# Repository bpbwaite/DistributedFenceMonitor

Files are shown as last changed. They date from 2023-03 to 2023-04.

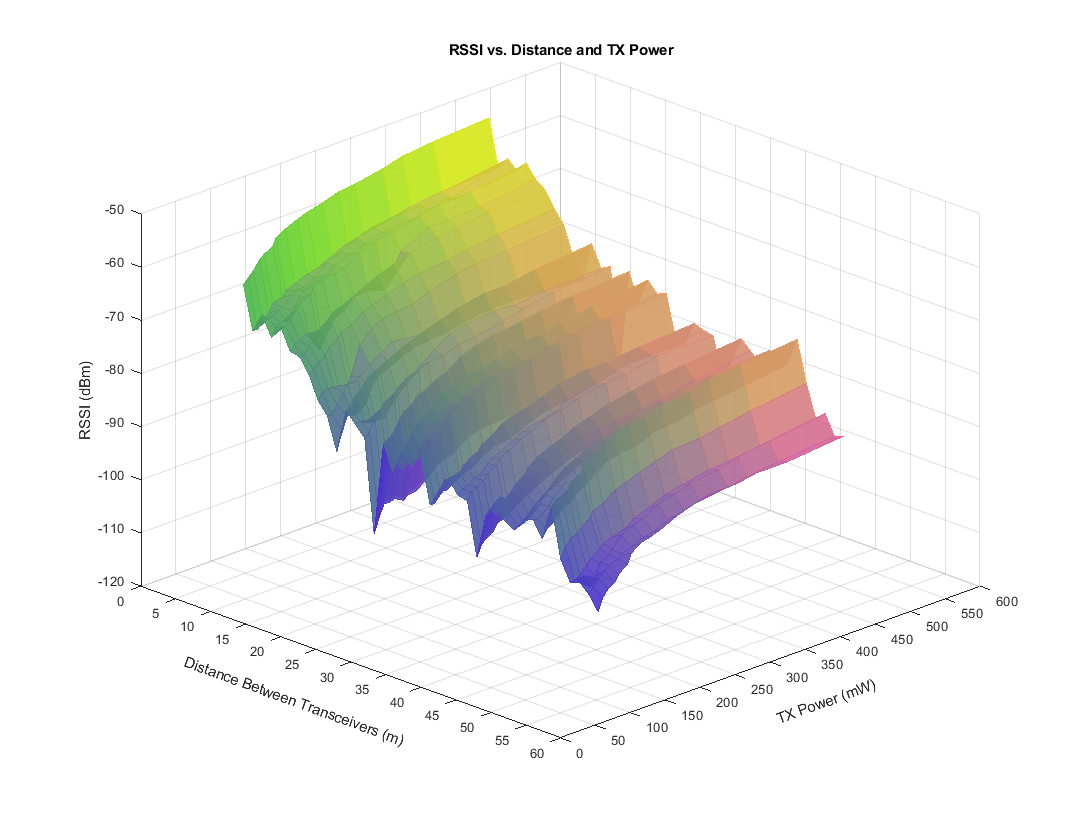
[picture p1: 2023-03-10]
interpreter/Improved Russey Tests/result.png

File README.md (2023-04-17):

# DistributedFenceMonitor

Repository for the Embry-Riddle Aeronautical University Distributed Fence Monitor Capstone.

*In Association with ICARUS and ERP.*

## How to Use

- The node source file is 'src/dfm_mkr1310.cpp'.
- The central-node source file is 'src/dfm_recv_mkr1310.cpp'.
- The central server file is 'interpreter/dfm_recv.m'
- The "main.cpp" is set up so that PlatformIO can compile and upload multiple sources separately, depending on the environment.

### Project Members

- Briellyn Braithwaite
- Jack Ramsay
- Lucas Marin
- Mike Paff
- Renzo Mena
- Zachary Couch

### Advisors

- Dr. Zapata
- Dr. Aranzazu
- Dr. Bruder
- Dr. Dorfling
- Dr. Sevic

## Configuration Features

All values settable in *dfm_mkr1310.h*

### System

- Node Identifier
- Peripheral Connection Reattempts (default: 5)
- Debug Interface on/off (default: on)
- Debug Interface Speed (default: 115200)
- Debug Interface Timeout (default: 10 sec)
- ADC Bit Depth (default: 10, max: 12)

### Motion Sensing

- Sample Rate (default: 100 Hz, max: 400 Hz)
- Sensitivity (default: 2g)
- Activity Threshold (default: 00007, min: 00002)
- Inactive Timer (default: 0.8 sec, min: 0.8)
- Severity Thresholds
- Resolution (default: 10 bit @ 256 LSB/g)

### Timing

- Reporting Interval (default: 15 sec, min: 5)
- Maximum Readings to Take (default: 2x)
- Sampling Duration (default: 500 samples, max: 2000)
- Data Timeout (default: 50 ms)

### Calibration

- Calibration Interval (default: 15 minutes, min: 1, max: 15)
- Calibration Duration (default: 300 samples)
- Calibration Time Slice (default: 0.5 sec, min: 0.5, max: 2.0)

### Low-Pass Filter

- Cutoff Frequency (default: 8 Hz)
- Impulse Response Length (default: 16)

### PCB Wiring Configuration

- Pinout
  - Mode pin (default: 2)
  - Status pin (default: 6)
  - Error pin (default: 3)
  - Battery pin (default: A1)
  - Switch pin (default: A5)
  - CS pin for ADXL1 (default: A3)
  - CS pin for ADXL2 (default: A4)
  - Interrupts pin (default: 7)
  - Temperature pin (default: 4)
- Resistor Voltage Divider Values (default: 680k/330k)

### LoRa Configuration

- Transmission Frequencies (default: 914.9 MHz)
- Transmission Power (default: 4dB, min: 2, max: 17)
- Acknowledgement Timeout (default: 1 sec)
- Reject CRC Failures (default: false)
- Bandwidth (default: 125kHz, max: 250kHz)
- Spreadfactor (default: 7, min: 7, max: 12)
- Syncword (default: 0012)

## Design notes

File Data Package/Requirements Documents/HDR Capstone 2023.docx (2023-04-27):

# Hardware Design Requirements

# Distributed Fence Vibration Monitor System

Version 1.1

Prepared by

B. Braithwaite

L. Marin

Embry-Riddle Aeronautical University

# 1 Introduction: High-Level Architecture

## 1.1 Purpose, Intended Audience and Reading Suggestions.

This document will serve as a reference to how the hardware is connected and configured along with requirements that drive those parameters. The intended audience are those continuing the development of this system and those who are maintaining this system. This document is intended to be read as a set of requirements and primary reference to other documentation, the goal is to describe how the system was designed.

## 1.2 Operating Environment

The end product is being designed for use in South African game reserves. But these requirements are set for a proof of concept system that will be used in the area of Prescott Arizona, primarily during the ERAU fall and spring semesters by students and faculty for research purposes.

## 1.3 Assumptions and Dependencies

This document largely assumes that the platform in use has already been determined and is the MKR1310. These requirements assume that this is a research project that will be used by ERAU students and faculty. Because this system will be deployed for relatively small scale research, it is assumed that all components in the system will be easily accessible for maintenance and repairs.

## 1.4 Product Scope & Constraints

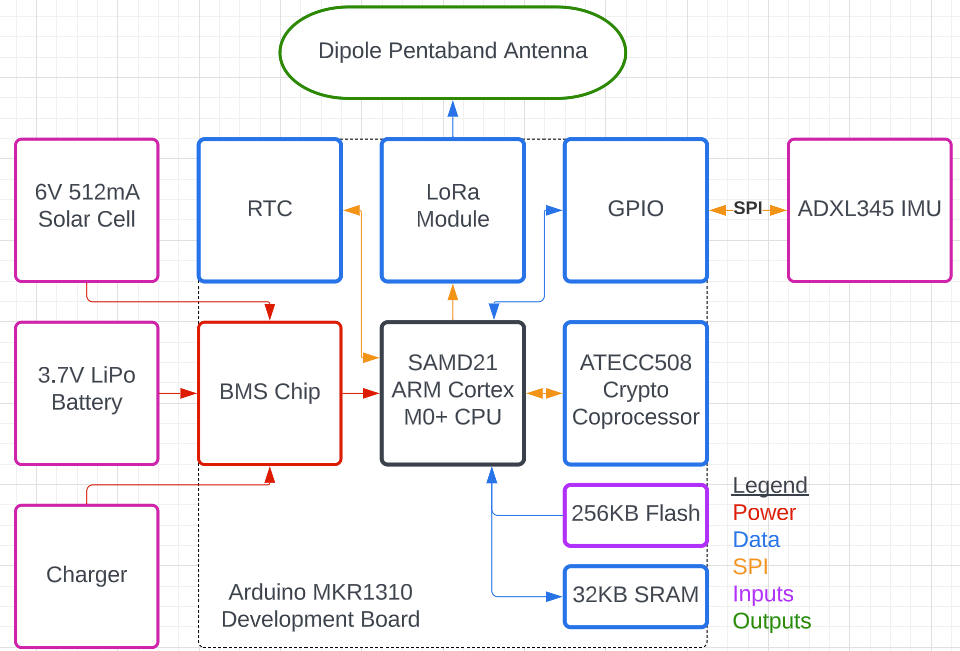
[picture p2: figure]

Figure 1 - Implementation Specific High-Level Hardware Diagram

# 2 Hardware Features

## 2.1 Individual Nodes Hardware

MKR1310 Device | Minimum Value | Preferred Value
Power Connectors | On-board battery connector (mini-JST) | USB, JST, terminal or barrel
Accelerometer Compatibility | ADXL345 | ADXL345, ADXL355
Wireless Capability | LoRa | LoRa
Headers | Optional | 10 for test, 30 I/O
Mode Switches | Mode switch | Yes (DIP switch, various)
Programmability | Micro-USB | Micro-USB
Debug Interfaces | Optional | Serial/UART or JTAG
Mounting Options | PCB mounting holes | PCB mounting holes, protective case

## 2.2 Central Server Hardware

The central receiver is physically similar to one of the nodes, but does not need the sensor capabilities, as the central receiver is loaded with a unique program to differentiate it from the nodes.

MKR1310 Device | Minimum Value | Preferred Value
Wireless Capability | LoRa | LoRa
Mode Switches | None | Mode Switch
Programmability & Interfacing | Micro-USB | Micro-USB

# 3 Physical & Mechanical Requirement Specifications

HR 1 The device shall be inexpensive
  1.1. Developmental units cost $135 each
  1.2. First SMD prototype expected to cost ~$40
HR 2 The device shall be self-contained
  2.1. Any computer, sensors, antenna, battery, and solar are all to be affixed in or on the unit
  2.2. There is no wired tethering to another device when operating
  2.3. Should electrical grounding be necessary, the device may simply contact the fence
HR 3 The device shall be weatherproof
  3.1. The housing of the unit shall be water and dust resistant to IP66 standards
  3.2. Temperature resistance
  3.3. UV resistance (don’t melt or discolor)
HR 4 The device shall be easy to install
  4.1. One person can handle multiple (5-10) units at a time
    4.1.1. The casing of the units must be stackable
  4.2. The units must be easy to transport
    4.2.1. [NTH] Fit snugly in a rectangular crate
  4.3. Each unit shall weigh less than 400g
  4.4. Installation must be repeatable
    4.4.1. Attachment to the fence is facilitated by a reusable clip

# 4 Electrical Requirement Specifications

HR 5 The device must accept energy from multiple power sources
  5.1. Battery management system (BMS): capable of battery, solar, and charging
  5.2. Solar panel in the range 5-7 V, capable of 512mA
    5.2.1. The MKR1310 BMS requires 512mA to charge a battery [1]
    5.2.2. 2-4A is recommended for greater efficiency [1]
  5.3. A Lithium-Polymer (LiPo) battery [2]
    5.3.1. Nominal voltage 3.7V-3.8V
    5.3.2. At least 1024mAh capacity [2]
    5.3.3. The battery must supply at least 150mA when loaded down to 3.3V
    5.3.4. The LoRa module may consume 128mA [1], and we need some overhead
    5.3.5. Absolute minimum viability: 48 hours
  5.4. [NTH] USB charger capable of 5V ±5% and at least 1000mA DC
HR 6 The device shall decouple from its power supply
  6.1. A 200uF decoupling cap on 5V rail has been recommended by many to avoid tripping OCP at high transmission strengths
HR 7 The device shall be capable of multiple power modes
  7.1. Power consumption is measured WRT the 3.3V rail
  7.2. ULP sleep mode
    7.2.1. ~100 µA [2]
  7.3. Processing mode
    7.3.1. 6-30 mA [3]
  7.4. High power transmitting mode
    7.4.1. Up to 128 mA [1] with Power Amplifier Boost

# 5 Hardware Requirement Specifications

HR 8 The device must contain a microcomputer
  8.1. A flash memory capable of holding the compiled software as described in the SRS document
  8.2. Processing ability to perform the functions as described in the SRS
    8.2.1. With interrupt abilities
    8.2.2. With RTC abilities
HR 9 The device must implement an accelerometer or IMU
  9.1. The maximum sampling rate must be at least 80 Hz
HR 10 The device must implement an RF transceiver
  10.1. Radio communications shall adhere to local regulations
  10.2. The radio must implement American (915MHz) and African (868MHz) LoRa frequencies
HR 11 The prototype shall be built upon a useful PCB platform
  11.1. The PCB must have power and status indicator LEDs
  11.2. There must be a physical switch to facilitate any changes in modes or configuration

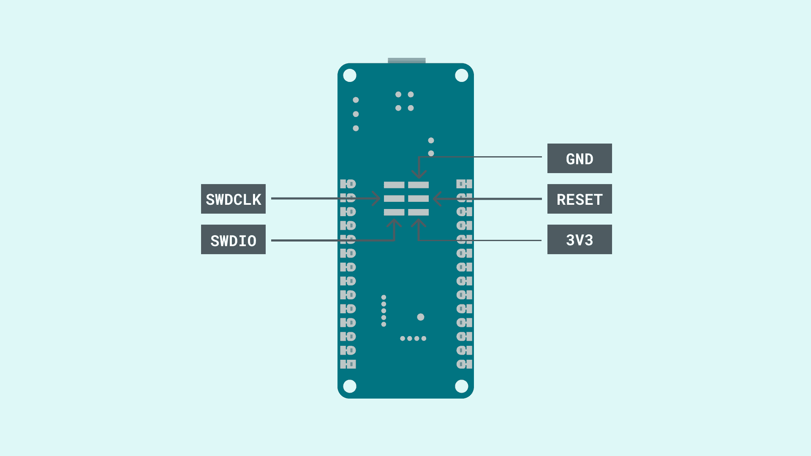
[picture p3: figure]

  11.3. The board must extend and support the MCU SWD interface [4]

Figure 2 - MKR1310 JTAG Interface Pinout

# 6 Acronyms and Abbreviations

The below table contains acronyms and abbreviations used in this document.

| Abbreviation | Description
A | ADC | Analog to Digital Converter
| ADXL | Analog Devices accelerometer
| AGC | Automatic Gain Control
B | BER | Bit Error Rate
| BLE | Bluetooth Low Energy
| BMS | Battery Management System
| BW | Bandwidth
C | CLK | Clock
| CPU | Central Processing Unit
| CRC | Cyclic Redundancy Check
D | dBm | Decibel Milliwatts
| DAC | Digital to Analog Converter
| DC | Direct Current
| DFM | Distributed Fence Monitor
| DIP | Dual In-line Package
E | EEPROM | Electrically Erasable Programmable Read-Only Memory
| EasyEDA | Schematic capture and circuit board design software
F | FCC | Federal Communications Commission
| FIFO | First In, First Out
| FSK | Frequency-shift Keying
| FXOSC | Frequency of Crystal Oscillator
G | g | grams
| GPIO | General Purpose Input/Output
H | HDR | Hardware Design Requirements
I | I2C, IIC | Inter-Integrated Circuit
| IC | Integrated Circuit
| IO, I/O | Input/Output
| IP | Ingress Protection rating
| IRQ | Interrupt Request
J | JST | Japan Solderless Terminal
| JTAG | Joint Test Action Group
K | kHz | Kilohertz
L | LED | Light Emitting Diode
| LiPo | Lithium Polymer battery
| LNA | Low Noise Amplifier
| LoRa | Long Range low-power wide-area network
M | mA | milliamperes
| mAh | milliamp Hour
| MCU | Micro Controller
| MHz | Megahertz
| MISO | Main In, Serial Out
| MKR1310 | An Arduino development platform with LoRa
| MOSI | Main Out, Serial In
| MPU | Motion Processing Unit
N | NTH | Nice To Have
O | OCP | Overcurrent Protection
| OOK | On-off keying
| OTA | Over the Air
P | PA | Power Amplifier
| PCB | Printed Circuit Board
| PLL | Phase-Locked Loop
| PMIC | Power Management Integrated Circuit
| PSU | Power Supply
R | RAM, SRAM | Random Access Memory
| RF | Radio Frequency
| RSSI | Received Signal Strength Indicator
| RTC | Real Time Clock
| RX | Receive
S | SF | Spread Factor
| SMD | Surface Mount Device
| SNR | Signal to Noise Ratio
| SPI | Serial Peripheral Interface
| SRS | Software Requirements Specifications
| SW | Synchronization Word
| SWD | Serial Wire Debug
T | TOA | Time on Air
| TRNG | True Random Number Generator
| TX | Transmit
U | uA, µA | microamperes
| UART | Universal Asynchronous Receiver-Transmitter
| uF, µF | microfarads
| ULP | Ultra Low Power
| USB | Universal Serial Bus
| UV | Ultraviolet Light
| uW, µW | microwatts
V | V | Volts
W | WAN | Wide Area Network
| WDT | Watchdog Timer
| WRT | With Respect To

# 7 Revision History

Date | Revision | Changes
1/26/2023 | 1.0 | First Release
2/9/2023 | 1.1 | Draft

# 8 References

[1] | FCC, "Arduino MKR WAN 1310 Product Datasheet," 2020. [Online]. Available: https://fcc.report/FCC-ID/2AN9S-ABX00029/5077682.pdf.
[2] | Arduino S.r.l., "Arduino MKR WAN 1310," 2021. [Online]. Available: https://store-usa.arduino.cc/products/arduino-mkr-wan-1310?selectedStore=us.
[3] | Microchip Technology Inc., "SAM D21 Family," 2018. [Online]. Available: https://content.arduino.cc/assets/mkr-microchip_samd21_family_full_datasheet-ds40001882d.pdf.
[4] | Arduino, "Debugging SAM-Based Arduino Boards with Atmel-ICE," 2023. [Online]. Available: https://docs.arduino.cc/tutorials/mkr-wifi-1010/atmel-ice.

006-0119-02 Hardware Design Requirements Documentation 2

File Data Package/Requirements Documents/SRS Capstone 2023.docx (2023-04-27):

# Software Requirements Specification

# Distributed Fence Vibration Monitor System

Version 1.1

Prepared by

J. Ramsay

B. Braithwaite

R. Mena

M. Paff

Embry-Riddle Aeronautical University

# 1 Introduction

## 1.1 Purpose

The purpose of the Software Requirement Specification is to provide documentation for the software aspects of the Distributed Fence Vibration System. This document provides both non-functional and functional requirements. It is intended to be used to reference the functionality and design of the system within the scope of hardware and software. The document will present software specifications for the individual nodes and its components and the central server as a secondary requirement.

## 1.2 Document Conventions

Refer to [CML for style guide] for reference to design.

## 1.3 Intended Audience and Reading Suggestions

This Software Requirements Specification (SRS) document is primarily intended for the engineering team and design leads. It is suggested that this document be read with and referenced with the Hardware Requirement Specifications.

## 1.4 Programming Environment

The components of the system shall be programmed using Visual Studio Code version 1.75. The MKR1310 as well as the RP2040 will be independent of each other with environments set up within an extension called Platform IO that is supported by Visual Studio Code. Platform IO is an extension that will allow for building and uploading of Arduino libraries and scripts for the individual boards. The Arduino mbed OS Nano board manager and the Arduino SAMD 32-bit Cortex M0+ will be installed from the Arduino IDE but supported and managed by Platform IO within Visual Studio Code. The files for each board consists of a header file and a source code file. Additional build flags in a configuration file enable advanced setup.

## 1.5 Dependency Tree

- Source Files
  - dfm_mkr1310.cpp
    - dfm_mkr1310.h
    - adafruit_ADXL345_U.h
    - Arduino.h
      - ArduinoCore API for ….
    - ArduinoECCX08.h
    - ArduinoLowPower.h
    - LoRa.h
      - SPI.h
    - RTCZero.h
      - SPI.h
  - dfm_nanorp2040.cpp
    - Arduino.h
    - Arduino_LSM6DSOX.h
    - WiFiNINA.h
  - dfm_vecv_mkr1310.cpp
    - Arduino.h
    - ARduinoECCX08.h
    - LoRa.h
    - SPI.h
  - dfm_recv_nanorp2040.cpp
    - Arduino.h
    - WiFiNINA.h
  - main.cpp
    - Arduino.h
    - dfm_vecv_mkr1310.h
    - dfm_nanorp2040.h

# 2 System Features (Functional Requirements)

## 2.1 Motion Detection

The software shall include a feature that detects motion from the chosen IMU and convert that motion into readable and transcribe data to then be used for other requirements. The software will include and depend on the libraries given from the chosen board and the components. This system feature holds the highest priority of all other software features as it is the core fundamental aspect of the project. The motion detection shall be interpreted and managed by the MKR1310 (or RP2040).

## 2.2 Communication

Communication between each of the nodes and the central server will be done by LoRa and a created struct contained within the dfm_mkr1310.h file will be transmitted using LoRa. This struct contains the information of the nodes. Each node will be in sleep mode until a hardware ISR occurs from the ADXL345 or another IMU and once the node is awake, after a synchronous clock trigger occurs, the awaken node with send a signal to other nodes to perform a state transition from sleep to awake.

## 2.3 Individual Nodes

Each individual node will need to be able to communicate with other nodes and be able to communicate within a central server. The nodes will be able to manage and control their power consumption and status.

SR 1 A node will communicate with other nearby nodes as part of a larger network.
  1.1. A node will attempt to use LoRa to communicate with a central server, or hub.
  1.2. A node out of range of the hub may use LoRa to communicate with other nodes.
SR 2 A node will have two modes: Active and Sleep.
  2.1. A node will switch to Active mode when a hardware interrupt is received from a sensor.
    2.1.1. The sensor is an IMU with a fixed motion threshold.
  2.2. A node will analyze the vibration data and determine whether or not it is an attack.
  2.3. Whether the node determines that the vibration is an attack or not, it notifies the central server.
  2.4. A node will switch to Sleep mode when no interrupts occur for a configurable amount of time.
SR 3 The system shall monitor vibrations for intrusions.
  3.1. The system shall detect vibrations via the accelerometer.
    3.1.1. Power density? Fourier Analysis? Thresholds?
    3.1.2. Rolling-buffer memory, FFT
    3.1.3. Have an EE help you here.
  3.2. When vibrations matching an intrusion pattern are detected, the node will send out an alert.
  3.3. Alerts are comprised of a packet containing a status.
    3.3.1. Status describes the severity of the attack.
SR 4 The system shall report when a node has become disconnected.
  4.1. A disconnected node is a node that is no longer sending or receiving signals.
SR 5 Each node shall periodically report diagnostics to the system.
  5.1. A node shall report its battery level as a percentage of its full charge.
  5.2. A node shall report its internal temperature in degrees Celsius.
  5.3. A node shall report its uptime, time spent awake, and time spent transmitting.
  5.4. A node shall report its configuration:
    5.4.1. Transmitting frequency and Sync Word (SW, similar to a channel)
    5.4.2. Epoch time as noted by its RTC
    5.4.3. Spread Factor (SF)
SR 6 A node shall have an identifier that can be used to determine its relative location.
  6.1. Adjacent nodes shall have an ID that differs by 1.
SR 7 A node shall communicate by broadcasting a packet.
  7.1. Nodes shall relay the packets sent by other nodes (if they are awake).
  7.2. Each packet sent shall have a unique ID.
    7.2.1. To avoid infinitely cascading signals, a node shall not relay subsequent signals received with an identical ID.
    7.2.2. When a node relays a signal, the node shall record the unique ID of that signal in a buffer.

## 2.4 Central Server & Reporting Dashboard

Though not being fully designed and produced for at this time, the requirement for the central nodes consists of the fence nodes communicating with the central server. The central server will be for data processing outside of each individual node.

SR 8 The server shall receive information from an arbitrary number of nodes.
SR 9 The server shall record the data transmitted from the nodes.
  9.1. The record is transmitted via USB to a file on a computer.
  9.2. Data collected from received packets:
    9.2.1. Timestamp
    9.2.2. Packet author
    9.2.3. Sequence number
    9.2.4. Status
    9.2.5. Battery level
    9.2.6. Configuration information
SR 10 The server shall recognize when a node needs attention or repair.
  10.1. [NTH] Notify personnel.
SR 11 [NTH] The system shall correct the real-time clock value of improperly set nodes.

# 3 Non-Functional Requirements

## 3.1 Performance Requirements

SR 12 [NTH] The system shall dynamically adjust power consumption to meet production in order to operate indefinitely.

## 3.2 Safety Requirements

SR 13 The software must not cause damage to the hardware.
  13.1. (I mean it’s pretty hard to do on accident but good idea nonetheless)
SR 14 All software shall be provably able to run indefinitely without encountering critical errors.

## 3.3 Security Requirements

SR 15 [NTH] The system shall implement time-varying rolling-codes to prevent a replay attack.
SR 16 [NTH] The software will utilize the ATECC508 cryptographic co-processor to ensure that the data that is being transmitted is secure. ///////Remove this!!!!!!!!!!!
  16.1. The system shall utilize a fixed packet structure to format data received from the nodes.
  16.2. The system shall implement time-varying rolling-codes to prevent a replay attack.
  16.3. The system shall intermittently send obfuscating data to prevent pattern recognition attacks.
SR 17 [NTH] Very old packet IDs can be ignored or reported as an attempted replay attack.
SR 18 [NTH] Intentional run-down detection.

## 3.4 Software Quality Attributes

SR 19 The software will be able to run indefinitely without encountering serious errors.
SR 20 The software will be able to run smoothly on the specified processor.
SR 21 The actual code shall be neatly maintained.
  21.1. GitHub synchronization
  21.2. Automatic Formatting
    21.2.1. K&R Indentation
SR 22 All libraries must be open source.
  22.1. MIT or LGPL Licenses
  22.2. Libraries shall not be modified

# 4 Analysis Models

Use Case ID: | UC-IN-1
Use Case Name: | Individual Nodes - Communication
Created By: | Renzo Mena | Last Updated By: | Renzo Mena
Date Created: | 1/23/2023 | Date Last Updated: | 1/24/2023

Actor: | The System/ Individual node
Description: | Once the system is linked to the network, it should be able to connect to other nearby nodes. After the link is established, the system should be able to communicate and inform the network of discrepancies (i.e., disconnected nodes, the system being under attack, and vibrations due to intrusions). Along with abnormalities the system will report its own status (i.e., diagnostics, battery level, and location relative to other nodes)
Preconditions: | The system is setup, configured, and linked to the network.
Postconditions: | The system reports any abnormalities and basic information to the server and other nodes
Priority: | High
Frequency of Use: | Routine
Normal Course of Events: | 1. System runs diagnostics and report to the server. 2. Battery life is relayed to the server. 3. Vibration monitoring
Alternative Courses: | 1. Disconnected node is detected and is reported. 2. System attack is detected and is reported. 3. Intrusion is detected and is reported.
Exceptions: | None
Includes: | None
Special Requirements: | None
Assumptions: | The system was successfully configured and is in working condition.
Notes and Issues: | None

Use Case ID: | UC-CSRD-1
Use Case Name: | Central Server & Reporting Dashboard
Created By: | Renzo Mena | Last Updated By: | Renzo Mena
Date Created: | 1/23/2023 | Date Last Updated: | 1/24/2023

Actor: | The server
Description: | The server receives and records data transmitted from multiple nodes. Also, if the server receives an alert for repair or damages from a node, personnel will be contacted and sent to the location
Preconditions: | A links to the server and nodes are established via LoRaWAN
Postconditions: | The server continuously receives information and report to personnel
Priority: | High
Frequency of Use: | Constant
Normal Course of Events: | 1. The server records information 2. Personnel is informed and sent to location
Alternative Courses: | None
Exceptions: | None
Includes: | Individual nodes
Special Requirements: | None
Assumptions: | Server and nodes are properly configured, and the connection is stable
Notes and Issues: | None

# 5 Glossary

The below table contains acronyms and abbreviations used in this document.

Abbreviation | Description
ID | Identifier
IDE | Integrated Development Environment
IMU | Inertial Measurement Unit
IO | Input/Output
LoRa | Long Range proprietary radio communication technique
LoRaWAN | IoT, Low power Wide Area Networking protocol
NTH | Nice To Have
OS | Operating System
RTC | Real Time Clock
SRS | Software Requirements Specification

# 6 Revision History

Date | Revision | Changes
1/25/2023 | 1.0 | First Release
2/??/2023 | 1.1 | (changes after Jaffe reviews it)

# 8 References

006-0119-01 Software Requirements Specification Documentation 2

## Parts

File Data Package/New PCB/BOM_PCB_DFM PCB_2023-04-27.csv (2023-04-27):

ID | Name | Designator | Footprint | Quantity | Manufacturer Part | Manufacturer | Supplier | Supplier Part | Price | Pins | 3DModel | Contributor | Resistance (Ohms) | image | link
1 | 100nF | C1 | C0603 | 1 | 0603B104K500NT | FH(风华) | LCSC | C30926 |  | 2 | C0603_L1.6-W0.8-H0.8 | lcsc |  |  | https://item.szlcsc.com/362304.html
2 | 220uF | C2 | CAP-SMD_BD6.3-L6.6-W6.6-FD | 1 | RVT1A221M0605 | ROQANG(容强) | LCSC | C72494 | 0.006 | 2 | CAP-SMD_BD6.3-L6.6-W6.6-FD | lcsc |  |  | https://item.szlcsc.com/265679.html
3 | S2B-PH-SM4-TB(LF)(SN) | CN1 | CONN-SMD_P2.00_S2B-PH-SM4-TB-LF-SN | 1 | S2B-PH-SM4-TB(LF)(SN) | JST | LCSC | C295747 | 0.03 | 4 | CONN-SMD_P2.00_S2B-PH-SM4-TB-LF-SN | LCSC |  |  | https://item.szlcsc.com/280164.html
4 | SZYY0603R | ERROR | LED0603-R-RD | 1 | SZYY0603R | yongyu(永裕光电) | LCSC | C434419 | 0.001 | 2 | LED0603-R-RD | LCSC |  |  | https://lcsc.com/product-detail/Light-Emitting-Diodes-LED_Hubei-KENTO-Elec-0603-Green_C12624.html
5 | 1kΩ | R2 | R0805 | 1 | 0805W8F1001T5E | UNI-ROYAL(厚声) | LCSC | C17513 |  | 2 | R0805_L2.0-W1.3-H0.6 | lcsc | 1K |  | https://item.szlcsc.com/142685.html
6 | 330kΩ | R6 | R0805 | 1 | 0805W8F3303T5E | UNI-ROYAL(厚声) | LCSC | C17629 |  | 2 | R0805_L2.0-W1.3-H0.6 | lcsc | 330K |  | https://item.szlcsc.com/142685.html
7 | 680kΩ | R7 | R0805 | 1 | 0805W8F6803T5E | UNI-ROYAL(厚声) | LCSC | C17797 |  | 2 | R0805_L2.0-W1.3-H0.6 | lcsc | 680K |  | https://item.szlcsc.com/142685.html
8 | KH-6X6X5H-STM | RESET,SWA6,SWA5 | SW-SMD_4P-L6.0-W6.0-P4.50-LS9.0-2 | 3 | KH-6X6X5H-STM | kinghelm(金航标) | LCSC | C2837531 | 0.003 | 4 | SW-SMD_4P-L6.0-W6.0-P4.50-LS11.0 | LCSC |  |  | https://so.szlcsc.com/global.html?c=&k=C620319
9 | HDR-F-2.54_1x8 | ADXL1,ADXL2,MPU | HDR-F-2.54_1X8 | 3 |  |  | LCSC | C225505 | 0.029 | 8 | HDR-F-2.54_1x8 | LCEDA_Lib
10 | HDR-F-2.54_2x6 | ADXL355 | HDR-F-2.54_2X6 | 1 |  |  | LCSC | C36191 | 0.012 | 12 | HDR-F-2.54_2x6 | LCEDA_Lib
11 | DB301V-5.0-2P-BU-P | VIN | CONN-TH_2P-P5.00_DB301V-5.0-2P-BU-P | 1 | DB301V-5.0-2P-BU-P | DIBO | LCSC | C430621 | 0.015 | 2 | CONN-TH_2P-P5.00_DB301V-5.0-2P-BU-P | LCSC |  |  | https://item.szlcsc.com/426266.html
12 | HDR-F-2.54_1x15 | H0 | HDR-F-2.54_1X15 | 1 |  |  | LCSC | C124408 | 0.034 | 15 | HDR-F-2.54_1x15 | LCEDA_Lib
13 | HDR-M-2.54_1x2 | J1 | HDR-M-2.54_1X2 | 1 |  |  | LCSC | C124375 | 0.004 | 2 | HDR-M-2.54_1x2 | LCEDA_Lib

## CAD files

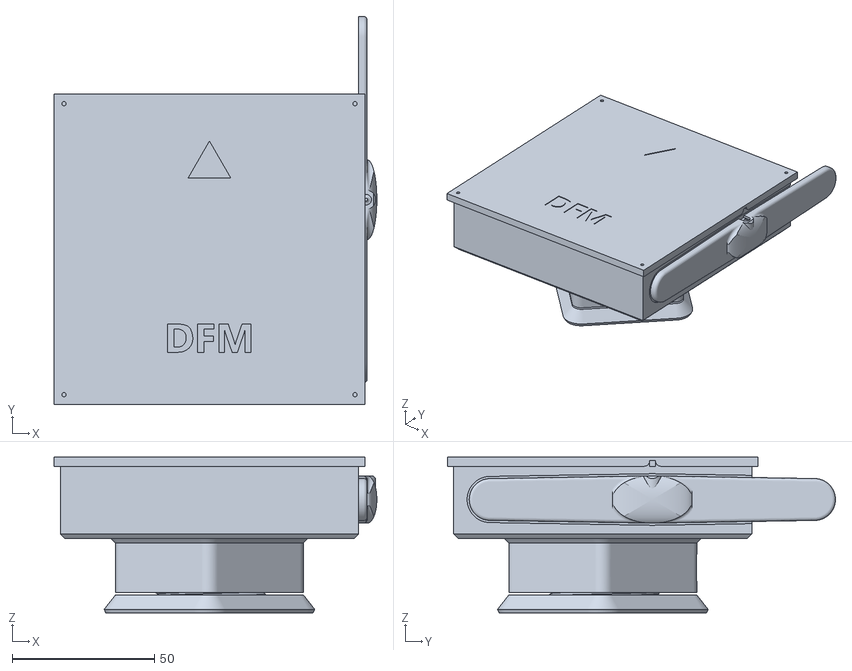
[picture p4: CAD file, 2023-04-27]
Data Package/Models/Bri/case v5 large.stl
113.4 x 136.3 x 54.8

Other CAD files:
Data Package/Models/Zac/base v5.f3d
Data Package/Models/Zac/lid v2.f3d
Data Package/Models/Zac/lid_lid v1.f3d

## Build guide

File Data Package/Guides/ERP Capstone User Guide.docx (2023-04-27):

# Distributed Fence Monitor

# User & Developer Guide

In Association with ICARUS

ERP Capstone

April 2023

B. Braithwaite - M. Paff- L. Marin

# 1 Hardware

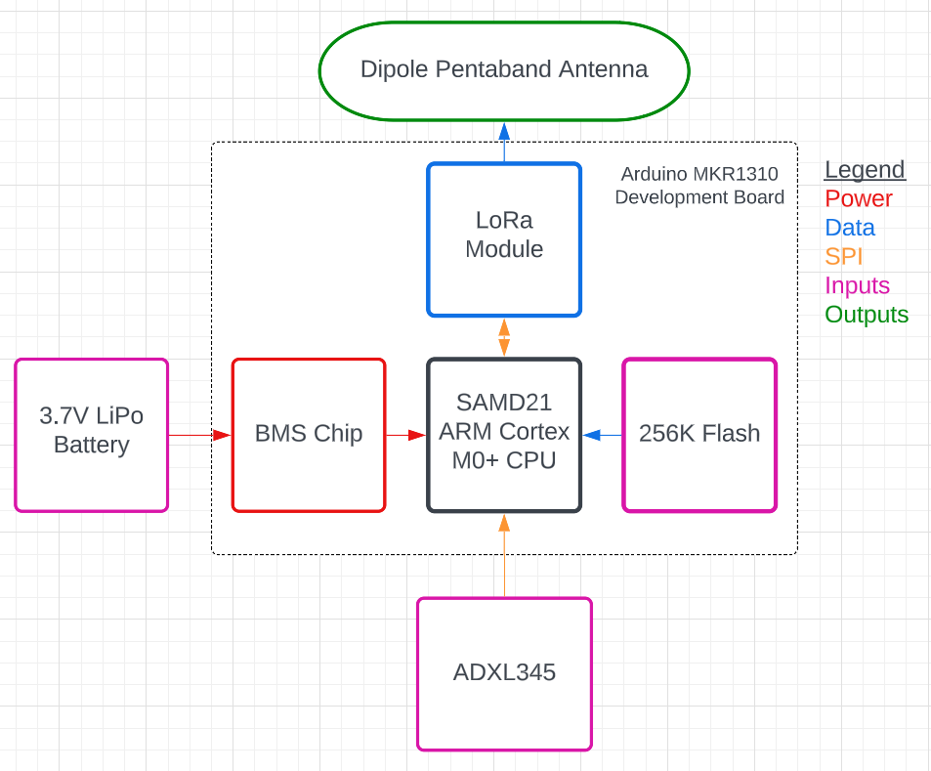
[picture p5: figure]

## 1.1 High Level Architecture

# 2 Printed Circuit Board

## 2.1 PCB Description & Details

- The PCB is made of 100mm x 100mm x 1.6mm FR4. The solder mask and conformal coating are lead-free. Follow the schematic for resistor and capacitor values when soldering.
- Design rules dictate the track width for power signals. For 1 oz/ft² copper, a tool was used to estimate that 0.6mm tracks are safe in warm environments even at the maximum current draw of 130mA.
- The PCB has separate inputs for power supplies (6V to 7V, uses VIN pin) and batteries (3.3V to 4.2V, must connect J1 Jumper to JST connector on MKR).
- On V1 of the PCB, certain aspects of the hardware can be toggled using a series of DIP switches. There are many options because the exact sensor and interface was unknown at the time of its design.

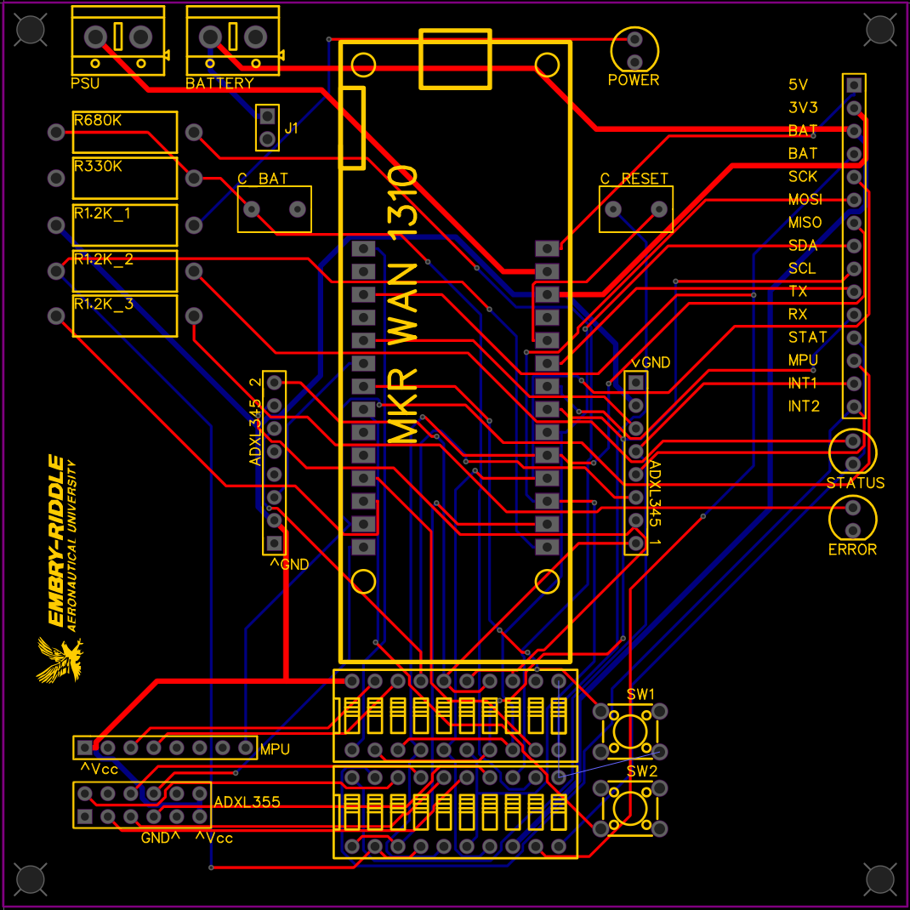
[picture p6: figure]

## 2.2 Configuration via DIP Switches

Please remove power before making configuration changes.

Block 1:

# | 1 | 2 | 3 | 4 | 5 | 6 | 7 | 8 | 9 | 10

On | Tie AREF pin to VCC (3.3V) | Connect MPU6050 over I2C. Ensure both 2 and 3 are enabled | | Connect ADXL345 over SPI. Ensure 4, 5, and 6 are all enabled | | | Connect ADXL345 over I2C. Ensure both 7 and 8 are enabled | | Tie MODE (pin 2) to GND. Can allow setting LoRa channel, for example. | Decouples RESET. The board is locked and may not be programmed
Off | Allows AREF pin to float | Disconnect MPU6050 I2C interface. Ensure both 2 and 3 are disabled | | Disconnect ADXL345 SPI interface. Ensure 4, 5, and 6 are all disabled | | | Disconnect ADXL345 I2C interface. Ensure both 7 and 8 are disabled | | MODE pin is pulled HIGH, if set in software | Unlock RESET capacitor. Allows board to be programmed

Block 2:

# | 1 | 2 | 3 | 4 | 5 | 6 | 7 | 8 | 9 | 10

On | Connect ADXL345 INT1 to pin 7. Ensure pin 3 is off! | Connect ADXL345 INT2 to pin 6. Ensure pin 4 is off! Note: this is also the LED_BUILTIN pin | Connect ADXL355 INT1 to pin 7. Ensure pin 1 is off! | Connect ADXL355 INT2 to pin 6. Ensure pin 2 is off! Note: this is also the LED_BUILTIN pin | Connect ADXL355 over SPI. Ensure 5, 6, and 7 are all enabled. | | | Battery input connects to voltage divider | An ADC (pin A1) connects to voltage divider | No effect, due to an error
Off | ADXL345 INT1 is disconnected | ADXL345 INT2 is disconnected | ADXL355 INT1 is disconnected | ADXL355 INT2 is disconnected | Disconnect ADXL355 SPI interface. Ensure 5, 6, and 7 are all disabled. | | | No reason to have off; draw is minimal | Pin A1 is freed from voltage divider | No effect

## 2.3 Mistakes on PCB V1

- There are spots for 2 tactile momentary switches on the board. The switch labeled SW2 will never work because it has no grounding.
- The on-PCB status LED cannot turn on because it depends on switch 10 being on, which, due to a ground-island routing error, has no grounding. You can just use the built-in LED on the MKR board; they are the same pin.
- The top layer of the PCB has no solid copper zone. It looks bad, and this could’ve fixed the previous issue.

## 2.4 Potential Improvements for V2

- Reduce side length from 100mm to 75mm
- Use SMD resistors, capacitors, momentary buttons, and LEDs
- Add a ground-plane strip for clipping oscilloscope probes
- Add a temperature sensor
- Add the proper type of JST battery connector
- Add a power supply capacitor
- Add a reset button (the little one on the board can be hard to see)
- The reset-decoupling capacitor is unnecessary. Unlike other Arduino boards, the MKR series has one built in
- Find a way to connect the battery more easily to both the board and the voltage divider to measure it
- Use different pins for interrupt to not conflict with the built-in LED

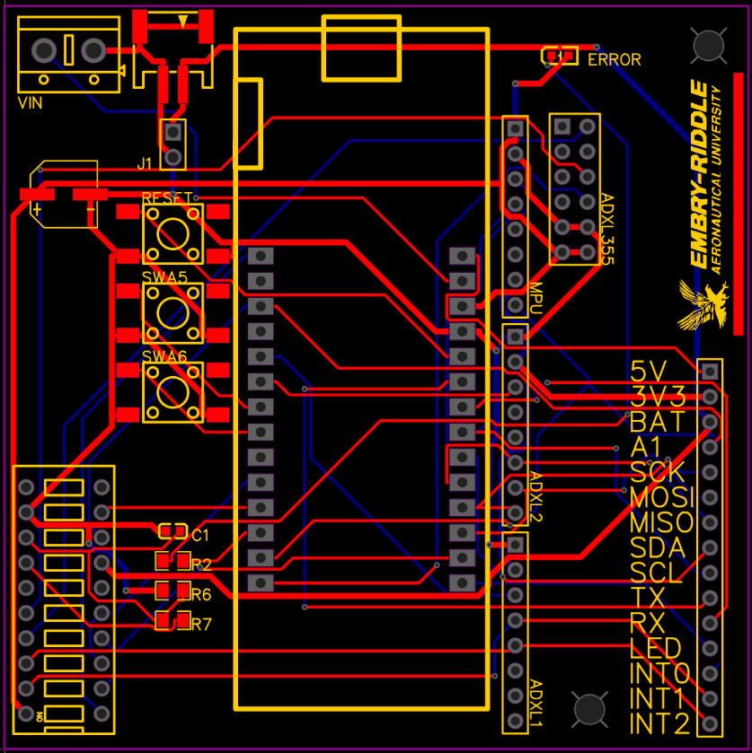
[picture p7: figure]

We mostly finished designing this PCB, but there was no time to order before symposium. EasyEDA files including the BOM should be included in the deliverables package.

# 3 Software

## 3.1 How to set up Environment

- Install Arduino IDE 2.0
- Within Arduino IDE 2.0, get Arduino SAMD boards Core (required driver)

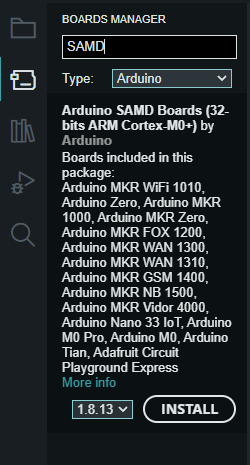
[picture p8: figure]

- Install git
- Install Visual Studio Code
- Within VS Code, get the PlatformIO extension
- Within VS Code, get the GitHub extension
- Clone the repo
- Open the project folder in VS Code and PIO will automatically get dependencies (give it a minute)
- Select the environment (node, central) on the lower ribbon

## 3.2 Basic Node Configuration

We strive to keep every useful value you might want to configure visible and highly adjustable. Below is a copy of the configuration features from the repository README:

System

- Node Identifier
- Peripheral Connection Reattempts (default: 5)
- Debug Interface on/off (default: on)
- Debug Interface Speed (default: 115200)
- Debug Interface Timeout (default: 10 sec)
- ADC Bit Depth (default: 10, max: 12)

Motion Sensing

- Sample Rate (default: 100 Hz, max: 400 Hz)
- Sensitivity (default: 2g)
- Activity Threshold (default: 00007, min: 00002)
- Inactive Timer (default: 0.8 sec, min: 0.8)
- Severity Thresholds
- Resolution (default: 10 bit @ 256 LSB/g)

Timing

- Reporting Interval (default: 15 sec, min: 5)
- Maximum Readings to Take (default: 2x)
- Sampling Duration (default: 500 samples, max: 2000)
- Data Timeout (default: 50 ms)

Calibration

- Calibration Interval (default: 15 minutes, min: 1, max: 15)
- Calibration Duration (default: 300 samples)
- Calibration Time Slice (default: 0.5 sec, min: 0.5, max: 2.0)
- Low-Pass Filter
- Cutoff Frequency (default: 8 Hz)
- Impulse Response Length (default: 16)

PCB Wiring Configuration

- Pinout
- Mode pin (default: 2)
- Status pin (default: 6)
- Error pin (default: 3)
- Battery pin (default: A1)
- Switch pin (default: A5)
- CS pin for ADXL1 (default: A3)
- CS pin for ADXL2 (default: A4)
- Interrupts pin (default: 7)
- Temperature pin (default: 4)
- Resistor Voltage Divider Values (default: 680k/330k)

LoRa Configuration

- Transmission Frequencies (default: 914.9 MHz)
- Transmission Power (default: 4dB, min: 2, max: 17)
- Acknowledgement Timeout (default: 1 sec)
- Reject CRC Failures (default: false)
- Bandwidth (default: 125kHz, max: 250kHz)
- Spreadfactor (default: 7, min: 7, max: 12)
- Syncword (default: 0012)

## 3.3 Severity Levels

Severity levels are spaced logarithmically between the minimum power to wake the node and the max power for the sensor, 0 being nothing and 15 being max severity. Each severity level requires around 50% more power than the previous level.

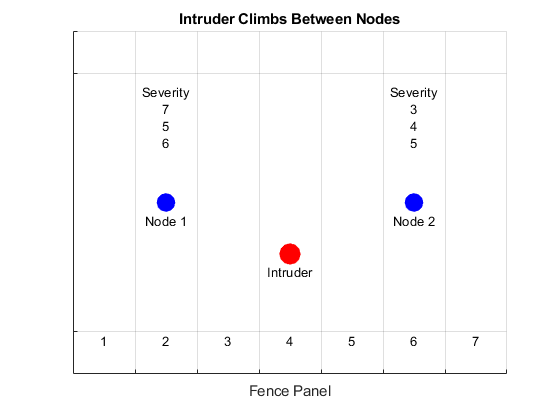
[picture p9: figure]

Figure 1: A test where an intruder climbed the fence in between the two nodes.

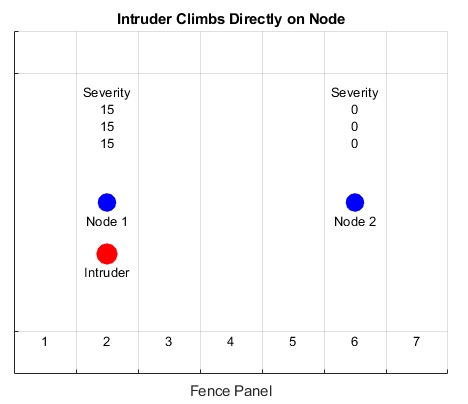
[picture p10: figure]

Figure 2: A test where an intruder climbed the fence directly on a node

# 4 Appendix

Link to repository

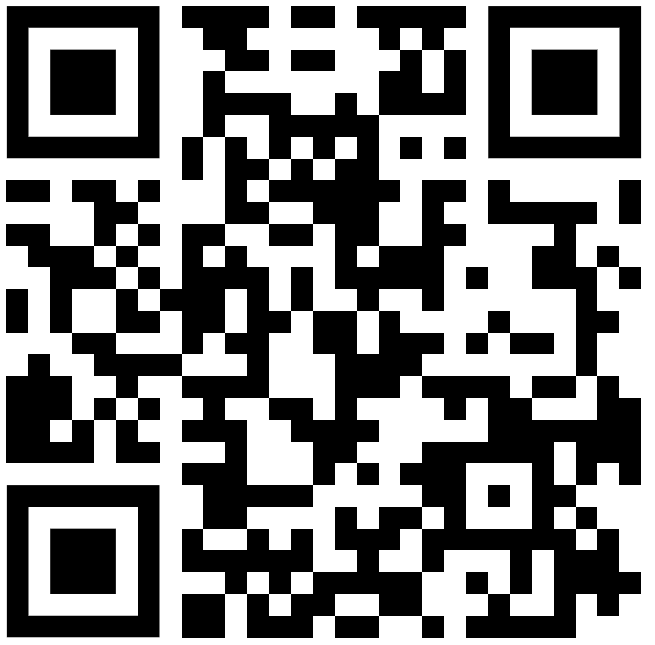
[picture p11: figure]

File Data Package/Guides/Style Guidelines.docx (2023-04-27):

# Style Guidelines

Distributed Fence Monitor Capstone

Briellyn Braithwaite

Embry-Riddle Aeronautical University

# 1 General

## 1.1 Consistency

For consistency, all styles must be set to automatically update when modified. It is a good idea to use this document as a starting point for future documents.

## 1.2 Margins

Margins are to be narrow. It gives us more space to work with but is wide enough for most printers.

## 1.3 Page Breaks

Add a page break between major headings.

## 1.4 The Table of Contents

The table of contents should start on the first page immediately after the title page. It does not get a number, and it’s heading does not get included in the TOC. The fonts are that of Heading-1 and Normal. There are two levels, indented so that the numbers of the second are aligned with the text of the first.

# 2 Fonts

## 2.1 Document Title

The document title shall be centered or right aligned, size 32pt SF Pro Display font. Zero spacing before and after, 1.5 between, and 4 returns from the top of the page. Text below the title has no specific font, but it must be smaller than the title. Sizes 11-14 are preferred, and document pairs should match.

## 2.2 Headings

The higher-level headings are left-aligned, size 18pt Arial Nova font, bold, with the whole-line underline enabled. The tier 2 headings are reduced to size 14pt and have decimal numbers on the left. They’ve also been given 3pt after-spacing.

## 2.3 Body Text

Body text is size 11pt Proxima Nova. Arial Nova also acceptable, but do not mix in one document. This also applies to the style in the TOC and any tables.

## 2.4 Subtitles & Captions

Captions are Times New Roman 9pt font in the color “black text 1 lighter 50%”, centered beneath the figure.

## 2.5 Document Header

The CML header and page numbers shall be Times New Roman 10pt, bold, italicized.

# 3 Numbering

## 3.1 Example

Look at how nice the numbers are on this document. Do this so that the TOC is automatically updating!

# 4 Tables

Use one of the two styles below as appropriate. Center them on the page. Right-click, table properties, Alignment: center, OK

Example Data Table | Conditions | Result

Example Appendix | Details

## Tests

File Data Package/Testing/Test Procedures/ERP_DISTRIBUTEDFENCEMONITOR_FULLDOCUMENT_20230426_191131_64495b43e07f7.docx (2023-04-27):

# ERP - Distributed Fence Monitor

A Embry-Riddle Aeronautical University project.

FULL DOCUMENT

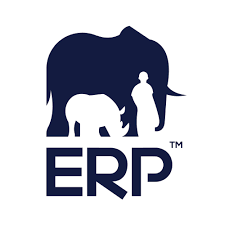
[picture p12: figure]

Function | By | Date | Sign
Author | Lucas Marin

Index

Figure index

Figure 1 9

Figure 2 10

Figure 3 11

Figure 4 14

Figure 5 29

# 1 Terminology used in the document

Applicable Documents | Applicable documents are those specification, standards, criteria etc. used to define the requirement
EQF | Environmental Qualification Form
Equipment | The term “equipment” includes the Units and all of the components necessary (as determined by the equipment manufacturer) for the equipment to properly perform its intended function(s).
Estimated stabilization time | Is the time required by the unit to change (in his biggest inertia part) the temperature from Maximum Storage Temperature to Minimum Storage Temperature after a long storage at high temperature.
EUT | Equipment Under Test
Reference Documents | Reference Documents are those documents included for information purpose; they provide insight into the operation, characteristics and interfaces, as well as relevant background information
Sample | Is a part of an Unit
Sample Group | Is a set of samples, composed by two or more samples
TBD | To Be Defined
Unit | Is the element to be qualified
Unit Group | Is a set of units, composed by two or more units
UUT | Unit Under Test, is the unit (or Sample, or Unit Group or Sample Group) that is subjected to tests

# 2 Project overview

## 2.1 Project description

Our capstone team, ERP - Distributed Fence Monitor, is designing and building a module that attaches to a fence and, when it detects vibrations, sends an alert and the appropriate response can be taken.

## 2.2 Environments for project

The product will be used in the following environments:

- Other/Unknown;

## 2.3 Aircraft Type

- Unknown

## 2.4 Number of tests

The total number of test described in this document is: 1

## 2.5 Number of UUT

This project has 1 UUT distributed as follows:

Units

1

# 3 Document Info

This Document was compiled by:

- https://app.do160.org Software rev. 1.6.0 of 2022/Jun/27
- Customer data of 2023/Apr/12

Ref. | Name | Type | Last Changes | Rev | Description
§ 2 | ERP - Distributed Fence Monitor | Project | 2023/Apr/26 | 1.3
§ 4.1 | Erp_Distributed_Fence_Monitor_Node_1_2023-04-07 | Unit | 2023/Apr/12 | 1.2
§ 5.1 | RTCA DO 357:2014 User Guide Supplement To Do-160G | Reference Document | 2023/Apr/07 | 1.0
§ 5.2 | Standard DO160 | Applicable Document | 2023/Apr/07 | 1.0
§ 6.1 | Power_Supply_Setup01 | Setup | 2023/Apr/11 | 1.4
§ 7.1 | Board_Test_01 | Functional Test | 2023/Apr/10 | 1.6
§ 7.2 | Case_Test_01 | Functional Test | 2023/Apr/11 | 1.7
§ 7.3 | Case_Test_02 | Functional Test | 2023/Apr/07 | 1.1
§ 7.4 | Board_Test_03 | Functional Test | 2023/Apr/10 | 1.4
§ 7.5 | Battery_Test_01 | Functional Test | 2023/Apr/10 | 1.4
§ 7.6 | Battery_Test_02 | Functional Test | 2023/Apr/07 | 1.1
§ 7.7 | Board_Test_02 | Functional Test | 2023/Apr/10 | 1.1
§ 12 | Test interruption for environmental test methods | Page | 2023/Apr/07 | 1.0
§ 13 | System of Units and Numeric Convention Used in this Document | Page | 2023/Apr/07 | 1.0
§ 17.1 | Temperature Variation (Sec.5 - Temperature Variation 001) | Test | 2023/Apr/12 | 1.5

# 4 Units

## 4.1 Erp_Distributed_Fence_Monitor_Node_1_2023-04-07

Part number: Node_1

### 4.1.1 Weight

Unit | Weight
Kilograms | 0.23
Pounds | 0.51

### 4.1.2 Sizes

Unit | Width | Height | Depth
Millimeters | 11.01 | 37 | 143
Inches | 0.43 | 1.46 | 5.63

### 4.1.3 Input powers

Name | Max Current [A] | Special Requirements
Other voltage | .128

### 4.1.4 Details

Function Performed: The node will be placed in the thermal chamber and cycle through different power levels and temperatures. It will be expected to operate normally under the varying conditions.

Estimated stabilization time: 1 minute

Operating Altitude: 1636 m (5367 ft) (83.17 kPa)

### 4.1.5 Safety Risks

This chapter contain the list of risk specific for this Unit.

- High Temperatures;

# 5 Reference and applicable documents

## 5.1 Reference Documents

Reference Documents are those documents included for information purpose; they provide insight into the operation, characteristics and interfaces, as well as relevant background information.

Identification | Release | Date | Description
RTCA DO 357:2014 User Guide Supplement To Do-160G | G | 2014-12-16 | The purpose of this document is to provide users of DO-160G additional background information for the associated test procedures and requirements in DO-160G.

## 5.2 Applicable Documents

Applicable documents are those specification, standards, criteria etc. used to define the requirement.

Identification | Release | Date | Description
Standard DO160 | G | 2010-12-08 | Standard

# 6 Setups

This chapter describes the setup used to perform functional test.

## 6.1 Power_Supply_Setup01 - Power_Supply

### 6.1.1 Description

1) Set up the power supply in the thermal test room.
2)Set the power supply to either 3.3 or 4.2 volts, depending on the test being performed.

### 6.1.2 Instruments used for this setup

Instrument | Detail
Power Supply

### 6.1.3 Images

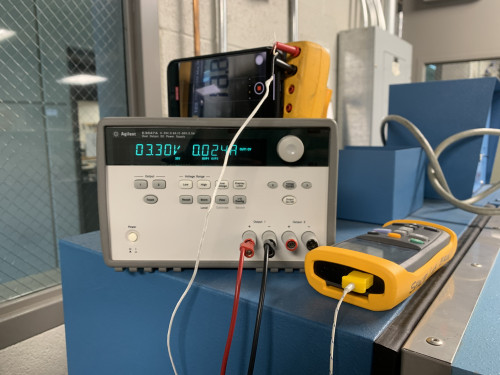
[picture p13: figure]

Figure 1

# 7 Functional Tests

This chapter describes the functional/operative tests to be performed during testing.

## 7.1 Board_Test_01 - Board_Test_01

### 7.1.1 Test Description

1. Visually inspect the board for any imperfections.
2. Put the board into the chamber.
3. Attach the thermocouple to the LORA CPU.

### 7.1.2 Pass Conditions

- No imperfections on the board;

### 7.1.3 Images

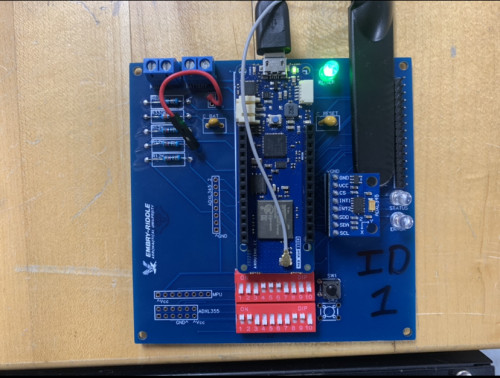
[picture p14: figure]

Figure 2

## 7.2 Case_Test_01 - Case_Test_01

### 7.2.1 Test Description

1. Visually inspect the case for any imperfections, and note them.
2. Put the case into the thermal chamber.

### 7.2.2 Pass Conditions

- Case is not compromised;

### 7.2.3 Images

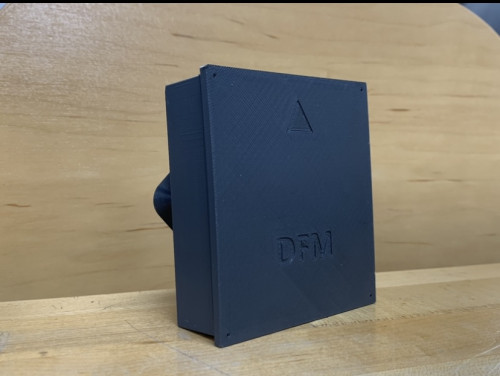
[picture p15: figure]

Figure 3

## 7.3 Case_Test_02 - Case_Test_02

### 7.3.1 Test Description

1. Remove the case from the thermal chamber.
2. Visually inspect the case to check for any imperfections not noted before.

### 7.3.2 Pass Conditions

- No new imperfections;

### 7.3.3 Operator

This functional test requires an operator, so it normally cannot be carried on during the night or during weekend.

## 7.4 Board_Test_03 - Board_Test_03

### 7.4.1 Test Description

1. Visually inspect the board for any imperfections not noted before.

### 7.4.2 Pass Conditions

- No new imperfections;
- Fail LED is not turned on;
- No reset detected;

## 7.5 Battery_Test_01 - Battery_Test_01

### 7.5.1 Test Description

1. Measure the voltage of the battery.
2. Put the battery in the thermal chamber.

### 7.5.2 Pass Conditions

- Battery voltage macthes;

### 7.5.3 Images

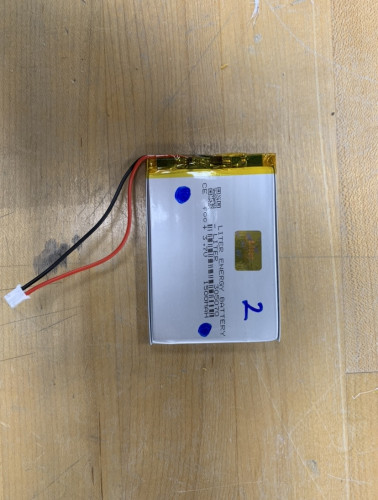
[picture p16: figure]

Figure 4

## 7.6 Battery_Test_02 - Battery_Test_02

### 7.6.1 Test Description

1. Remove the battery from the thermal chamber.
2. Measure the voltage of the battery.
3. Verify it matches the previous measurement.

### 7.6.2 Pass Conditions

- Battery voltages match;

## 7.7 Board_Test_02 - Board_Test_02

### 7.7.1 Test Description

1. Run (max power code) to transmit at max power every 5 seconds.

### 7.7.2 Pass Conditions

- Board cycles through power levels;

# 8 Correlation Between Functional Tests and Setups

Setup | Power_Supply_Setup01
Functional Test
Board_Test_01
Case_Test_01
Case_Test_02
Board_Test_03
Battery_Test_01
Battery_Test_02
Board_Test_02

# 9 Testing Laboratory Summary

This chapter provides information on where each test indicated in this document will be performed.

## 9.1 Unit Erp_Distributed_Fence_Monitor_Node_1_2023-04-07

Test (Identification) | Ref | Laboratory
Sec.5 Temperature Variation (Sec.5 - Temperature Variation 001) | 17.1 | Not Defined

# 10 List of test document used in this document

This chapter contain a cross reference between each test and used documentation.

| Test | §17.1
| DO160 G Section | 5
Document | Section
Standard DO160 | 5 | X
RTCA DO 357:2014 User Guide Supplement To Do-160G | 5 | X

# 11 Safety Risk for test described in this document

The Test indicated in this document can be dangerous for person, or can spride risk. In this chapter a list of risk for each test is described.

Test | §17.1
DO160 G Section | 5
Risk
Danger of very low temperatures | X
Danger of High Temperature | X

# 12 Test interruption for environmental test methods

The following procedures shall be followed when a test is interrupted. Explain test interruptions in the test report, and any deviation from the following information.

1. In-tolerance interruptions Interruption periods during which the prescribed test tolelrances (e.g. power interruptions that do not affect chamber temperature) do not constitute a test interruption. Therefore, do not modify the test duration if exposure to proper test levels was maintained during the ancillary interruption.
2. Out-of-tolerance interruptions
  - Undertest If test tolerances have been exceed resulting in an under test condition, the test may be resumed from the point at which tolerances were exceed following reestablishment of prescribed conditions (except as noted in the individual methods), and extended to insure that the prescribed test cycle is achieved by the test laboratory.
  - Overtest If the overtest was occurred, the test will be stopped during the test according to customer's chosen, and will be conducted an a functional checks according to § 7. if the functional checks results are compliant with the § 7, re start the test, otherwise the test will be performed with a new test article.  If any damage is a direct result of the over test conditions and will not affect other EUT characteristics, or if the EUT can be repaired, the test may be resumed and extended as in the under test condition.  If an item failure occurs during the remainder of the test, the test result shall be considered invalid.  For the ambient measurement into electromagnetics environments, the ambient electromagnetic level measured with the EUT de-energized and all auxiliary equipment turned on shall be at least 6 dB below the allowable specified limits when the tests are performed in a shielded enclosure.
3. Other environmental test methods set out in the document Each of these methods contains guidance for handling out-of-tolerance-test interruption. Any such interruption must be carefully analysed. If the decision is made to continue testing from the point interruption, to restart the last successfully completed test cycle, or to restart the entire test with the same EUT, and a failure occurs, it is essential to consider the possibility effect of the interruption or of the extended length of the test

# 13 System of Units and Numeric Convention Used in this Document

Numbers where defined using a dot: (For example 1/3= 0.333333333)

Thousands where defined with space. (For example 1 000 000)

The following units where used

- s - Seconds
- m - Meters
- kg - Kilograms
- Pa - Pascal
- F - Farad
- C - Coloumb
- A - Ampere
- V - Volt
- J - Joule
- N - Newton
- H - Henry
- T - Tesla
- w - Weber
- W - Watt
- Ohm - Ohm
- K - Kelvin
- Hz - Hertz

Factor Scale

- Kilo (k) = 1000
- Mega (M) = 1 000 000
- Giga (G) = 1 000 000 000
- micro (u) = 0.000 001
- nano (n) = 0.000 000 001
- pico (p) = 0.000 000 000 001

DATES FORMAT YYYY-MM-DD

# 14 Environmental Qualification Form

## 14.1 EQF for Erp_Distributed_Fence_Monitor_Node_1_2023-04-07

NOMENCLATURE | Erp_Distributed_Fence_Monitor_Node_1_2023-04-07
TYPE/MODEL/PART NO | Node_1
TSO NUMBER | __________________________________________
MANUFACTURER'S SPECIFICATION AND/OR OTHER APPLICABLE SPECIFICATION | __________________________________________ __________________________________________ __________________________________________ __________________________________________
MANUFACTURER | Embry-Riddle Aeronautical University
ADDRESS | __________________________________________
REVISION & CHANGE NUMBER OF DO-160 | DO 160 G
DATE TESTED | __________________________________________

Conditions | Sections | Description of tests conducted (Category)
DO160G - Temperature and Altitude | Sec.4 | Not performed/Applicable
Temperature Variation | Sec.5 | A
DO160G - Humidity | Sec.6 | Not performed/Applicable
DO160G - Operational Shocks and Crash Safety | Sec.7 | Not performed/Applicable
DO160G - Vibration | Sec.8 | Not performed/Applicable
DO160G - Explosive Atmosphere | Sec.9 | Not performed/Applicable
DO160G - Waterproofness | Sec.10 | Not performed/Applicable
DO160G - Fluids Susceptibility | Sec.11 | Not performed/Applicable
DO160G - Sand and Dust | Sec.12 | Not performed/Applicable
DO160G - Fungus Resistance | Sec.13 | Not performed/Applicable
DO160G - Salt Fog | Sec.14 | Not performed/Applicable
DO160G - Magnetic Effect | Sec.15 | Not performed/Applicable
DO160G - Power Input | Sec.16 | Not performed/Applicable
DO160G - Voltage Spike | Sec.17 | Not performed/Applicable
DO160G - Audio Frequency Conducted Susceptibility - Power Inputs | Sec.18 | Not performed/Applicable
DO160G - Induced Signal Susceptibility | Sec.19 | Not performed/Applicable
DO160G - Radio Frequency Susceptibility (Radiated and Conducted) | Sec.20 | Not performed/Applicable
DO160G - Emission of Radio Frequency Energy (Radiated and Conducted) | Sec.21 | Not performed/Applicable
DO160G - Lightning Induced Transient Susceptibility | Sec.22 | Not performed/Applicable
DO160G - Lightning Direct Effects | Sec.23 | Not performed/Applicable
DO160G - Icing | Sec.24 | Not performed/Applicable
DO160G - Electrostatic Discharge (ESD) | Sec.25 | Not performed/Applicable
DO160G - Fire and Flammability | Sec.26 | Not performed/Applicable

# 15 Section Category Cross Reference

This chapter contain information on the environment selected for each test.

## 15.1 Environments for Erp_Distributed_Fence_Monitor_Node_1_2023-04-07

Test | Sections | Description of Environment described in the section
Temperature Variation (Sec.5 - Temperature Variation 001) | Sec.5 | Category: A - For equipment external to the aircraft or internal to the aircraft: 10 degrees Celsius minimum per minute.

# 16 Test Sequence

## 16.1 Test Sequence for unit "Node_1 Erp_Distributed_Fence_Monitor_Node_1_2023-04-07"

### 16.1.1 Execute in this order

n. | Test Name | Section
1 | Temperature Variation Sec.5 - Temperature Variation 001 | Sec.5

# 17 Test requirement for unit Node_1 Erp_Distributed_Fence_Monitor_Node_1_2023-04-07

## 17.1 DO 160 G - Sec.5 - Temperature Variation - "Sec.5 - Temperature Variation 001"

Standard: | DO160 G
Section: | 5
Title: | Temperature Variation
Category: | A

### 17.1.1 Purpose of the test

This test determines performance characteristics of the equipment during temperature variations between high and low operating temperature extremes.

Note: The test is not intended to verify the behavior of the equipment in wet or icing conditions. In conducting this test, the test chamber may incorporate the capability of controlling or altering humidity to the extent that condensation is minimized or does not occur.

### 17.1.2 Reference Documents

Identification | Release
RTCA DO 357:2014 User Guide Supplement To Do-160G | G

### 17.1.3 Applicable Documents

Identification | Release
Standard DO160 | G

### 17.1.4 Test Procedure

1) Setup the unit as per [Power_Supply_Setup01 - Power_Supply (§ 6.1)];

2) Perform test as per [Board_Test_01 - Board_Test_01 (§ 7.1)];

3) Perform test as per [Case_Test_01 - Case_Test_01 (§ 7.2)];

4) Perform test as per [Battery_Test_01 - Battery_Test_01 (§ 7.5)];

5) Install the EUT in the climatic chamber

6) Install the UUT in chamber 2 as for [Board_Test_02 - Board_Test_02] [ONLY at cycle (1)]

7) Start at standard ambient temperature (22 °C | 54 °F)

8) Decrease the temperature in the chamber towards the operating low temperature level (0 °C | 32 °F) at the applicable rates of 4 degrees Celsius minimum per minute)

9) Increase the temperature in the chamber towards the operating high temperature level (50 °C | 82 °F) at the applicable rates of 4 degrees Celsius minimum per minute)

10) Switch off the UUT

11) Maintain the equipment in a non-operating state for 2 minutes

12) Turn the equipment on

13) Lower the temperature in the chamber towards the operating low temperature level (0 °C | 32 °F) at the applicable rates of 4 degrees Celsius minimum per minute)

14) Perform test [Board_Test_02 - Board_Test_02] [ONLY at cycle (1)]

15) Turn off the equipment

16) Wait 30 minutes

17) Switch on the UUT as per [Board_Test_02 - Board_Test_02] [ONLY at cycle (1)]

18) Change the temperature of the chamber towards the ambient temperature (22 °C | 54 °F) at the applicable rates of 4 degrees Celsius minimum per minute)

19) Repeat steps 7)..18) for another time (Total of 2 cycles)

20) Perform test as per [Board_Test_03 - Board_Test_03 (§ 7.4)];

21) Perform test as per [Case_Test_02 - Case_Test_02 (§ 7.3)];

22) Perform test as per [Battery_Test_02 - Battery_Test_02 (§ 7.6)];

### 17.1.5 Test Duration

Estimated test duration: 1 Day 3 Hours

### 17.1.6 Test Interruption

Continue with testing

### 17.1.7 Instruments

- From SETUP "Power_Supply_Setup01 - Power_Supply [§ 6.1]": Power Supply;
- Climatic Chamber;

### 17.1.8 Safety Risks

- Danger of very low temperatures;
- Danger of High Temperature;

### 17.1.9 Pass conditions

- [Before TEST] - from (Board_Test_01 - Board_Test_01 [§ 7.1]): No imperfections on the board;
- [Before TEST] - from (Case_Test_01 - Case_Test_01 [§ 7.2]): Case is not compromised;
- [Before TEST] - from (Battery_Test_01 - Battery_Test_01 [§ 7.5]): Battery voltage macthes;
- [During TEST] - from (Board_Test_02 - Board_Test_02 [§ 7.7]): Board cycles through power levels;
- [After TEST] - from (Board_Test_03 - Board_Test_03 [§ 7.4]): No new imperfections;
- [After TEST] - from (Board_Test_03 - Board_Test_03 [§ 7.4]): Fail LED is not turned on;
- [After TEST] - from (Board_Test_03 - Board_Test_03 [§ 7.4]): No reset detected;
- [After TEST] - from (Case_Test_02 - Case_Test_02 [§ 7.3]): No new imperfections;
- [After TEST] - from (Battery_Test_02 - Battery_Test_02 [§ 7.6]): Battery voltages match;

### 17.1.10 Test images

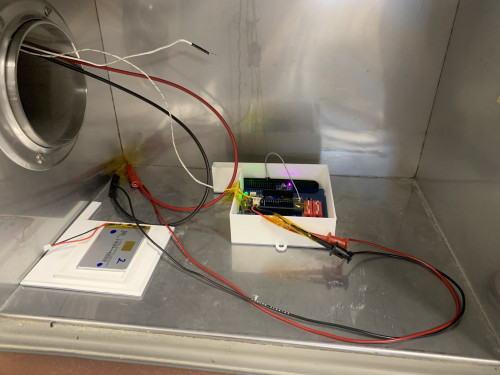
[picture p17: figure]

Figure 5

Embry-Riddle Aeronautical University Page 29 of 29 This document is property of Embry-Riddle Aeronautical University. Unauthorized reproduction or distribution is not permitted.

ERP - Distributed Fence Monitor - 2023-04-26 DO160 G DOCUMENT

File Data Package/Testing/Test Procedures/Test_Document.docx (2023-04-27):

# Testing Procedures

# Distributed Fence Vibration Monitor System

Version 1.2

Prepared by

L. Marin

Embry-Riddle Aeronautical University

# 1 Introduction

This document will go over several tests run on the product by the ERP team, to verify certain parts of the design before turning in a completed prototype.

# 2 Requirments

ID | Requirments
ER-1 | The electrical characteristics of the microcontroller and battery shall adhere to the following table. PARAMETER TEST CONDITIONS MIN TYP MAX UNIT Battery Supply Voltage 5 7 V CPU & I/O Voltage 1.62 3.3 3.63 V Supply Current Mode: Sleep 104 µA Mode: Processing 6 mA Mode: Transmitting 128
ER-2 | The electrical characteristics of the accelerometers shall adhere to the following table. Accelerometer Device Current at Nominal Voltage Estimated Power ADXL355 200 µA at 3.3V 0.66 mW ADXL345 130 µA at 2.5V (100Hz sampling) 0.364 mW
HR-1.1 | The minimum self-powered time (no servicing) for viability is 48 hours.
SR-1.2 | The server shall receive information from an arbitrary number of nodes.
SR-1.3 | The server shall record the data transmitted from the nodes.

# 3 Acceptance Tests

## 3.1 Purpose

The purpose of these tests is to verify conformance to the design. All tests will be performed indoors in a lab unless specified otherwise.

## 3.2 Test Case List

ID | Test Case
TC-1 | Verifies the power levels of the MKR1310 microcontroller
TC-2 | Verifies the power levels of the two accelerometer options
TC-3 | Verifies the power levels of the batteries
TC-4 | Verifies that the ISR is working properly
TC-5 | Verifies that the nodes can send and receive data

## 3.3 Test Requirements Matrix

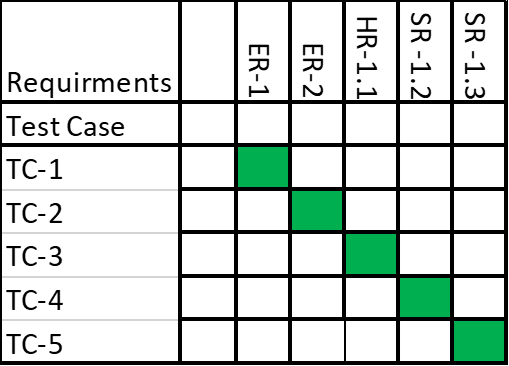
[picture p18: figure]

## 3.4 Required Equipment

a) Power Supply
b) Oscilloscope
c) Tektronix TCP2020
d) Multimeter
e) Jumper Wires

## 3.5 Test Cases

TC-1

Purpose/Description:

To verify that the MKR1310 microcontroller electrical specifications are within tolerance.

Stimulus:

a) Set the power supply to 6 volts.
b) Connect a current probe to one of the oscilloscopes channels and put the probe around the positive lead.
c) Connect another oscilloscope probe to pin six, the indicator pin, of the MKR1310.
d) Degauss the current probe.
e) Connect the power supply to the microcontroller.
f) Run test_2.cpp to cycle through all levels of transmission power.
g) Measure the current draw for each of the different transmission powers 17 in total.
h) Repeat steps a through f for the remaining microcontrollers.
i) Verify that the measured data is what was expected, which should be different peaks for each transmission strength.

Validation:

The MKR1310 currents had a min of 18mA and a max of 111mA.

Requirments Being Tested:

ER-1

TC-2

Purpose/Description:

To verify that the ADXL and MPU accelerometer electrical specifications are within tolerance.

Stimulus:

a) Set the power supply to 3.3 volts.
b) Attach the power supply to the accelerometer.
c) Record the measured current value.
d) Verify that the measured data is what was expected for each sensor.

Validation:

The ADXL had an average current draw of 0.0223mA and the MPU had an average draw of 1.667mA

Requirments Being Tested:

ER-2

TC-3

Purpose/Description:

To verify that the battery voltages are within tolerance.

Stimulus:

a) Probe the battery leads with the multimeter.
b) Measure both voltage and current from the battery.
c) Verify that they are correct for each battery.

Validation:

Requirments Being Tested:

HR-1.1

TC-4

Purpose/Description:

To verify that the ISR can be triggered in both sleep and wake modes

Stimulus:

a) Place the board on a flat stable surface.
b) Turn the board on.
c) While the board is in sleep mode, tap the board in a way that would trigger the ISR.
d) Confirm that the interrupt pin on the accelerometer went high.
e) Repeat steps c-d when the board is in wake mode.

Validation:

Requirments Being Tested:

SR-1.2

TC-5

Purpose/Description:

To verify that the module can send and receive data

Stimulus:

a) Place the board on a flat stable surface.
b) Send data to a board and have the array values printed out.
c) Verify that the values are the same as those that were transmitted.
d) Have the board send data to another board and verify that the receiving board is receiving.
e) Print the array values and verify that the values are the same as those that were transmitted.

Validation:

Both the sent and received arrays were the same.

Requirments Being Tested:

SR-1.3

# 4 References

Lets do references in IEEE format. Use word’s built in manager

Testing Procedures Documentation 2

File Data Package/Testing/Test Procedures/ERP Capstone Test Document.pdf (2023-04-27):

Testing Procedures Documentation 1

# Testing Procedures

# Distributed Fence Vibration Monitor System

## Version 1.0

## Prepared by L. Marin

## Embry-Riddle Aeronautical University

Testing Procedures Documentation 2

## Table of Contents

Testing Procedures Documentation 3

## 1 Acceptance Tests

### 1.1 Purpose

The purpose of these tests is to verify conformance to the design. All tests will be performed indoors in a lab unless specified otherwise.

### 1.2 Test Requirements Matrix

### 1.3 Required Equipment (will update with actual product names)

a) Power Supply
b) Oscilloscope
c) Tektronix TCP2020
d) Multimeter
e) Jumper Wires
Requirments | ES-1 | ES-2 | TS-3 | TS-4 | TS-5 | TS-6 | TS-7 | TS-8 | TS-9 | TS-10 | TS-11 | TS-12 | TS-13 | TS-14 | TS-15

Test Case
TC-1
TC-2
TC-3
TC-4
TC-5
TC-6
TC-7
TC-8
TC-9
TC-10
TC-11
TC-12
TC-13

Commented [BB1]: Current probe is "Tektronix TCP2020". In this section maybe note the precision required

Testing Procedures Documentation 4

### 1.4 Test Setup (MKR1310)

a) Set the power supply to 6 volts.
b) Connect a current probe to one of the oscilloscopes channels and put the probe around the positive lead.
c) Connect another oscilloscope probe to pin six, the indicator pin, of the MKR1310.
d) Degauss the current probe.
e) Connect the power supply to the microcontroller.
f) Run test_2.cpp to cycle through all levels of transmission power.
g) Measure the current draw for each of the different transmission powers 17 in total.
h) Repeat steps a through f for the remaining microcontrollers.
i) Verify that the measured data is what was expected, which should be different peaks for each transmission strength.

### 1.5 Test Setup (Accelerometer)

a) Set the power supply to 3.3 volts.
b) Attach the power supply to the accelerometer.
c) Record the measured current value.
d) Verify that the measured data is what was expected for each sensor.

### 1.6 Test Setup (Lithium Battery)

a) Probe the battery leads with the multimeter.
b) Measure both voltage and current from the battery.
c) Verify that they are correct for each battery.

### 1.7 Test Setup (Software)

Commented [BB2]: Maybe make note that this is the "indicator" pin

Commented [BB3]: Before this step, degauss/zero the probe
Commented [BB4]: The test file is called test_2.cpp. test_power is the Matlab script
Commented [BB5]: Combine with step E? and make note of setting the window on the scope, etc
Commented [BB6]: (a peak for each transmission strength)

Testing Procedures Documentation 5

## 2 Environmental Tests

### 2.1 Purpose

The purpose of these tests are to ensure that the environment will not be an issue when the finish product in put into service.

### 2.2 Test Setup (Casing) 2.2.1. IP6X

a) Fill a bucket with sand.
b) Attach module to a fence.
c) Check the inside of the enclosure for any dust.

### 2.2.2. IPX6

a) Get a hose with an internal nozzle diameter of 12.5mm and a flowrate of 100 l/min.
b) Spray the enclosure from 3m away for 3 minutes.
c) Check the inside of the enclosure for any water.

### 2.2.3. Heat

a) Put in thermal chamber at 50°C(122°F)

Testing Procedures Documentation 6

## 3 References

Lets do references in IEEE format. Use word’s built in manager

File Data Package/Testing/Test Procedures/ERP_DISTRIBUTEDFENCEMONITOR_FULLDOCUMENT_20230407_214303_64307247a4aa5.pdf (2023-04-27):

# ERP - Distributed Fence Monitor

A Embry-Riddle Aeronautical University project.

FULL DOCUMENT

Embry-Riddle
Aeronautical University

Page 1 of 28

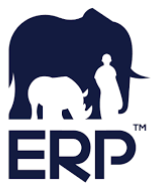
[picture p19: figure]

This document is property of Embry-Riddle Aeronautical University. Unauthorized reproduction or distribution is not permitted.

ERP - Distributed Fence Monitor - 2023-04-07

DO160 G DOCUMENT

## Index

Embry-Riddle

Page 2 of 28

Figure index

Embry-Riddle

Page 3 of 28

### 1 Terminology used in the document

Applicable Documents | Applicable documents are those specification, standards, criteria etc. used to define the requirement
EQF | Environmental Qualification Form
Equipment | The term “equipment” includes the Units and all of the components necessary (as determined by the equipment manufacturer) for the equipment to properly perform its intended function(s).
Estimated stabilization time | Is the time required by the unit to change (in his biggest inertia part) the temperature from Maximum Storage Temperature to Minimum Storage Temperature after a long storage at high temperature.
EUT | Equipment Under Test
Reference Documents | Reference Documents are those documents included for information purpose; they provide insight into the operation, characteristics and interfaces, as well as relevant background information
Sample | Is a part of an Unit
Sample Group | Is a set of samples, composed by two or more samples
TBD | To Be Defined
Unit | Is the element to be qualified
Unit Group | Is a set of units, composed by two or more units
UUT | Unit Under Test, is the unit (or Sample, or Unit Group or Sample Group) that is subjected to tests

Embry-Riddle

Page 4 of 28

### 2 Project overview

### 2.1 Project description

Our capstone team, ERP - Distributed Fence Monitor, is designing and building a module that attaches to a fence and, when it detects vibrations, sends an alert and the appropriate response can be taken.

### 2.2 Environments for project

The product will be used in the following environments:

- Other/Unknown;

### 2.3 Aircraft Type

- Unknown

### 2.4 Number of tests

The total number of test described in this document is: 1

### 2.5 Number of UUT

This project has 1 UUT distributed as follows:

Units
1

Embry-Riddle

Page 5 of 28

### 3 Document Info

This Document was compiled by:

- https://app.do160.org Software rev. 1.6.0 of 2022/Jun/27
- Customer data of 2023/Apr/07
Ref. | Name | Type | Last Changes | Rev | Description
§ 2 | ERP - Distributed Fence Monitor | Project | 2023/Apr/07 | 1.2
§ 4.1 | Erp_Distributed_ Fence_Monitor_ Node_1_2023-04-07 | Unit | 2023/Apr/07 | 1.0
§ 5.1 | RTCA DO 357:2014 User Guide Supplement To Do-160G | Reference Document | 2023/Apr/07 | 1.0
§ 5.2 | Standard DO160 | Applicable Document | 2023/Apr/07 | 1.0
§ 6.1 | Power_Supply_S etup01 | Setup | 2023/Apr/07 | 1.2
§ 7.1 | Board_Test_01 | Functional Test | 2023/Apr/07 | 1.3
§ 7.2 | Case_Test_01 | Functional Test | 2023/Apr/07 | 1.2
§ 7.3 | Case_Test_02 | Functional Test | 2023/Apr/07 | 1.1
§ 7.4 | Board_Test_03 | Functional Test | 2023/Apr/07 | 1.2
§ 7.5 | Battery_Test_01 | Functional Test | 2023/Apr/07 | 1.2
§ 7.6 | Battery_Test_02 | Functional Test | 2023/Apr/07 | 1.1
§ 7.7 | Board_Test_02 | Functional Test | 2023/Apr/07 | 1.0
§ 12 | Test interruption for environmental test methods | Page | 2023/Apr/07 | 1.0
§ 13 | System of Units and Numeric Convention Used in this Document | Page | 2023/Apr/07 | 1.0
§ 17.1 | Temperature Variation (Sec.5 -Temperature Variation 001) | Test | 2023/Apr/07 | 1.1

Embry-Riddle

Page 6 of 28

### 4 Units

### 4.1 Erp_Distributed_Fence_Monitor_Node_1_2023-04-07

Part number: Node_1

### 4.1.1 Weight

Unit | Weight
Kilograms | 0.4
Pounds | 0.88

### 4.1.2 Sizes

Unit | Width | Height | Depth
Millimeters | 101.6 | 177.8 | 76.2
Inches | 4 | 7 | 3

### 4.1.3 Input powers

Name | Max Current [A] | Special Requirements
Other voltage | 128mA

### 4.1.4 Details

Function Performed: The node will be placed in the thermal chamber and cycle through different power levels and temperatures. It will be expected to operate normally under the varying conditions. Estimated stabilization time: 4 minutes
Operating Altitude: 1034 m (3392 ft) (89.52 kPa)

### 4.1.5 Safety Risks

This chapter contain the list of risk specific for this Unit.

- High Temperatures;

Embry-Riddle

Page 7 of 28

### 5 Reference and applicable documents

### 5.1 Reference Documents

Reference Documents are those documents included for information purpose; they provide insight into the operation, characteristics and interfaces, as well as relevant background information.

Identification | Release | Date | Description
RTCA DO 357:2014 User Guide Supplement To Do-160G | G | 2014-12-16 | The purpose of this document is to provide users of DO-160G additional background information for the associated test procedures and requirements in DO-160G.

### 5.2 Applicable Documents

Applicable documents are those specification, standards, criteria etc. used to define the requirement.

Identification | Release | Date | Description
Standard DO160 | G | 2010-12-08 | Standard

Embry-Riddle

Page 8 of 28

### 6 Setups

This chapter describes the setup used to perform functional test.

### 6.1 Power_Supply_Setup01 - Power_Supply

### 6.1.1 Description

1) Set u the power supply in the thermal test room. 2)Set the power supply to cycle between 3.3V and 4.1V 3)
4)

### 6.1.2 Instruments used for this setup

Instrument | Detail
Power Supply

Embry-Riddle

Page 9 of 28

### 7 Functional Tests

This chapter describes the functional/operative tests to be performed during testing.

### 7.1 Board_Test_01 - Board_Test_01

### 7.1.1 Test Description

1. Visually inspect the board for any imperfections.
2. Run the (power test) on the board and record the results.
3. Put the board into the chamber.
4. Attach the thermocouple to (specified points on the board).

### 7.1.2 Pass Conditions

- Board does not exceed (required temp);

### 7.1.3 Safety Risks

The Test indicated in this document can be dangerous for person, or can spread risk. In this chapter a list of risk for all test described in this document are listed.

- Destroying the product;

Embry-Riddle

Page 10 of 28

### 7.2 Case_Test_01 - Case_Test_01

### 7.2.1 Test Description

1. Visually inspect the case for any imperfections, and note them.
2. Put the case into the thermal chamber.

### 7.2.2 Pass Conditions

- Case is not compromised;

Embry-Riddle

Page 11 of 28

### 7.3 Case_Test_02 - Case_Test_02

### 7.3.1 Test Description

1. Remove the case from the thermal chamber.
2. Visually inspect the case to check for any imperfections not noted before.

### 7.3.2 Pass Conditions

- No new imperfections;

### 7.3.3 Operator

This functional test requires an operator, so it normally cannot be carried on during the night or during weekend.

Embry-Riddle

Page 12 of 28

### 7.4 Board_Test_03 - Board_Test_03

### 7.4.1 Test Description

1. Visually inspect the board for any imperfections not noted before.
2. Run the (power test) and record the results.
3. Verify the data is the same as the previous test.

### 7.4.2 Pass Conditions

- No new imperfections;
- Board power is not effected;

Embry-Riddle

Page 13 of 28

### 7.5 Battery_Test_01 - Battery_Test_01

### 7.5.1 Test Description

1. Measure the voltage of the battery.
2. Put the battery in the thermal chamber.

### 7.5.2 Pass Conditions

- Battery voltage macthes;

Embry-Riddle

Page 14 of 28

### 7.6 Battery_Test_02 - Battery_Test_02

### 7.6.1 Test Description

1. Remove the battery from the thermal chamber.
2. Measure the voltage of the battery.
3. Verify it matches the previous measurement.

### 7.6.2 Pass Conditions

- Battery voltages match;

Embry-Riddle

Page 15 of 28

### 7.7 Board_Test_02 - Board_Test_02

### 7.7.1 Test Description

1. Run the (power test) to go through the different transmission levels.

### 7.7.2 Pass Conditions

- Board cycles through power levels;

Embry-Riddle

Page 16 of 28

### 8 Correlation Between Functional Tests and Setups

Setup | Power_Supply_Setup01
Functional Test
Board_Test_01
Case_Test_01
Case_Test_02
Board_Test_03
Battery_Test_01
Battery_Test_02
Board_Test_02

Embry-Riddle

Page 17 of 28

### 9 Testing Laboratory Summary

This chapter provides information on where each test indicated in this document will be performed.

### 9.1 Unit Erp_Distributed_Fence_Monitor_Node_1_2023-04-07

Test (Identification) | Ref | Laboratory
Sec.5 Temperature Variation (Sec.5 - Temperature Variation 001) | 17.1 | Not Defined

Embry-Riddle

Page 18 of 28

### 10 List of test document used in this document

This chapter contain a cross reference between each test and used documentation.

| Test | §17.1
| DO160 G Section | 5
Document | Section
Standard DO160 | 5 | X
RTCA DO 357:2014 User Guide Supplement To Do-160G | 5 | X

Embry-Riddle

Page 19 of 28

### 11 Safety Risk for test described in this document

The Test indicated in this document can be dangerous for person, or can spride risk. In this chapter a list of risk for each test is described.

Test | §17.1
DO160 G Section | 5
Risk
Danger of very low temperatures | X
Danger of High Temperature | X
From Functional Test Board_Test_01 - Board_Test_01: Destroying the product | X

Embry-Riddle

Page 20 of 28

### 12 Test interruption for environmental test methods

The following procedures shall be followed when a test is interrupted. Explain test interruptions in the test report, and any deviation from the following information.
1. In-tolerance interruptions
Interruption periods during which the prescribed test tolelrances (e.g. power interruptions that do not affect chamber temperature) do not constitute a test interruption. Therefore, do not modify the test duration if exposure to proper test levels was maintained during the ancillary interruption.
2. Out-of-tolerance interruptions
o Undertest
If test tolerances have been exceed resulting in an under test condition, the test may be resumed from the point at which tolerances were exceed following reestablishment of prescribed conditions (except as noted in the individual methods), and extended to insure that the prescribed test cycle is achieved by the test laboratory.
o Overtest
If the overtest was occurred, the test will be stopped during the test according to customer's chosen, and will be conducted an a functional checks according to § 7. if the functional checks results are compliant with the § 7, re start the test, otherwise the test will be performed with a new test article.

If any damage is a direct result of the over test conditions and will not affect other EUT characteristics, or if the EUT can be repaired, the test may be resumed and extended as in the under test condition.

If an item failure occurs during the remainder of the test, the test result shall be considered invalid.

For the ambient measurement into electromagnetics environments, the ambient electromagnetic level measured with the EUT de-energized and all auxiliary equipment turned on shall be at least 6 dB below the allowable specified limits when the tests are performed in a shielded enclosure.
3. Other environmental test methods set out in the document
Each of these methods contains guidance for handling out-of-tolerance-test interruption. Any such interruption must be carefully analysed. If the decision is made to continue testing from the point interruption, to restart the last successfully completed test cycle, or to restart the entire test with the same EUT, and a failure occurs, it is essential to consider the possibility effect of the interruption or of the extended length of the test

Embry-Riddle

Page 21 of 28

### 13 System of Units and Numeric Convention Used in this Document

Numbers where defined using a dot: (For example 1/3= 0.333333333)

Thousands where defined with space. (For example 1 000 000)

The following units where used

- s - Seconds
- m - Meters
- kg - Kilograms
- Pa - Pascal
- F - Farad
- C - Coloumb
- A - Ampere
- V - Volt
- J - Joule
- N - Newton
- H - Henry
- T - Tesla
- w - Weber
- W - Watt
- Ohm - Ohm
- K - Kelvin
- Hz - Hertz

Factor Scale

- Kilo (k) = 1000
- Mega (M) = 1 000 000
- Giga (G) = 1 000 000 000
- micro (u) = 0.000 001
- nano (n) = 0.000 000 001
- pico (p) = 0.000 000 000 001

DATES FORMAT YYYY-MM-DD

Embry-Riddle

Page 22 of 28

### 14 Environmental Qualification Form
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

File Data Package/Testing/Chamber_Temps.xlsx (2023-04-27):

 |  |  | Max temp: 50°C | chamber temo recorded with Fluke 189
3.3V Cold Start Time | 10:30:00 |  | Min temp: 0°C | CPU temp recodred with Fluke 52 II
3.3V Cold End Time | 11:30:00 |  |  | PSU is Agilent E3647A
THERMOCOUPLEs WERE 0.2 °C OFF |  |  | Max Voltage: 4.2V
Chamber Temperture ( °C) | CPU Temperature (°C) | Time | Min Voltage: 3.3V
20.4 | 20.6 | 10:30:00
-1.4 | 1.5 | 10:35:00
-0.8 | 1.1 | 10:40:00
-0.6 | 1.0 | 10:45:00
-0.4 | 0.9 | 10:50:00
-0.3 | 0.8 | 10:55:00
-0.3 | 0.9 | 11:00:00
-0.1 | 0.8 | 11:05:00
-0.1 | 0.8 | 11:10:00
-0.2 | 0.8 | 11:15:00
-0.2 | 0.8 | 11:20:00
-0.1 | 0.8 | 11:25:00
-0.2 | 0.8 | 11:30:00
4.2V Cold Start Time | 11:31:00
4.2V Cold End Time | 12:05:00
THERMOCOUPLEs WERE 0.2 °C OFF
Chamber Temperture ( °C) | CPU Temperature (°C) | Time
-0.2 | 0.9 | 11:35:00
-0.2 | 0.8 | 11:40:00
-0.1 | 0.9 | 11:45:00
-0.2 | 0.8 | 11:50:00
-0.2 | 0.8 | 11:55:00
-0.1 | 0.8 | 12:00:00
-0.2 | 0.8 | 12:05:00
3.3V Hot Start Time | 12:06:00
3.3V Hot End Time | 13:00:00
THERMOCOUPLEs WERE 0.2 °C OFF
Chamber Temperture ( °C) | CPU Temperature (°C) | Time
50.3 | 49.0 | 12:30:00
50.4 | 49.7 | 12:35:00
50.4 | 49.9 | 12:40:00
50.2 | 50.0 | 12:45:00
50.4 | 50.0 | 12:50:00
50.4 | 50.1 | 12:55:00
50.3 | 50.1 | 13:00:00
4.2V Hot Start Time | 13:01:00
4.2V Hot End Time | 13:35:00
THERMOCOUPLEs WERE 0.2 °C OFF
Chamber Temperture ( °C) | CPU Temperature (°C) | Time
50.4 | 50.2 | 13:05:00
50.4 | 50.2 | 13:10:00
50.3 | 50.3 | 13:15:00
50.4 | 50.3 | 13:20:00
50.4 | 50.2 | 13:25:00
50.4 | 50.4 | 13:30:00
50.4 | 50.4 | 13:35:00

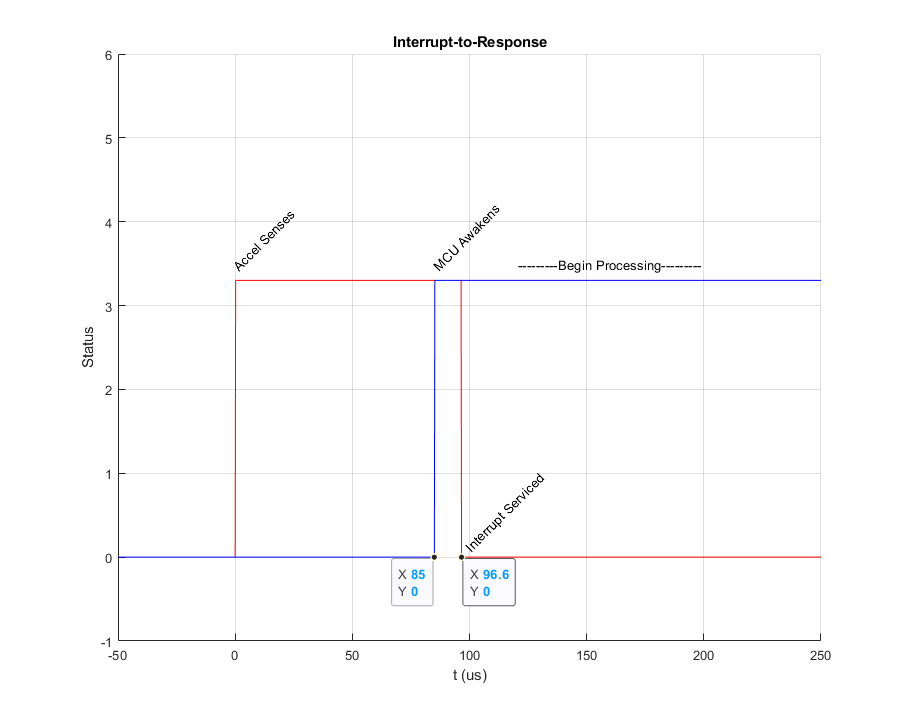
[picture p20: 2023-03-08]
interpreter/ISR Testing/itor.png

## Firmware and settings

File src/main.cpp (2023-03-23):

/*
  FILE: MAIN.CPP
  VERSION: 1.5.0
  DATE: 22 March 2023
  PROJECT: Distributed Fence Monitor Capstone
  AUTHORS: Briellyn Braithwaite
  DESCRIPTION:
*/

#include <Arduino.h>

#include "dfm_mkr1310.h"
#include "dfm_recv_mkr1310.h"

#ifndef PIO_UNIT_TESTING

void setup() {
    // put your setup code here, to run once:
#if defined(ARDUINO_SAMD_MKRWAN1310)
#if defined(CENTRAL_NODE)
    setup_recv_mkr1310();
#else
    setup_mkr1310();
#endif
#endif
}

void loop() {
    // put your main code here, to run repeatedly:
#if defined(ARDUINO_SAMD_MKRWAN1310)
#if defined(CENTRAL_NODE)
    loop_recv_mkr1310();
#else
    loop_mkr1310();
#endif
#endif
}

#endif

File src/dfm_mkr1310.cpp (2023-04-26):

/*
  FILE: DFM_MKR1310.CPP
  VERSION: 1.0.0
  DATE: 16 April 2023
  PROJECT: Distributed Fence Monitor Capstone
  AUTHORS: Briellyn Braithwaite, Jack Ramsay, Renzo Mena, Mike Paff
  DESCRIPTION: MKR1310 Node Code
*/
#include "dfm_mkr1310.h"
#include "dfm_errors.h"
#include "dfm_utils.h"

#if defined(ARDUINO_SAMD_MKRWAN1310) && !defined(CENTRAL_NODE)

#include <Arduino.h>
// do not sort includes!
// clang-format off
#include <Wire.h>
#include <SPI.h>
#include <RTCZero.h>
#include <ArduinoLowPower.h>
#include <Arduino_PMIC.h>
#include <LoRa.h>
#include <SparkFun_ADXL345.h>
#include <DHT.h>
// clang-format on

// only defines unique to nodes that vary from board to board

#define MY_IDENTIFIER 0x02 // 0-13; small scale build ID determines turn
#define SET_RTC       true

// global variables and objects
RTCZero rtc;
MND_Compact mnd;
MND_Ack mnd_response;
ADXL345 *adxl;
DHT *tSensor;

// System Counters

int adxlAttempts  = 0; // num times attempted to communicate with sensor
int attackCounter = 0;
uint32_t central_milliseconds;
uint32_t ms_offset;       // TODO compute and use ms offset to more accurately schedule wake
volatile int ackFlag = 0; // bytes received in acknowledgement

// Data collection items

int DC_offset = 0;
double Z_Power_Samples[ADXL_SAMPLE_LENGTH];
int severityLevel = 0;
double LPF_FIR[FIRSIZE];

// isr related items
volatile bool motionDetected = false;
volatile bool need_reattach  = false;

void wakeuphandler(void) {
    motionDetected = true;
}

// timing related items

uint32_t next_wake_epoch = 0;
uint32_t next_send_epoch = 0;
// init to zero so it is seen as past time to send

volatile unsigned long TOLR = 0; // time of last real-time-clock setting
inline unsigned long TSLR() {
    return millis() - TOLR;
} // time since last calibration
volatile unsigned long TOLC = 0; // time of last calibration
inline unsigned long TSLC() {
    return millis() - TOLC;
} // time since last calibration
volatile unsigned long TOLS = 0; // time of last sample
inline unsigned long TSLS() {
    return millis() - TOLS;
} // time since last sample
volatile unsigned long TOLA = 0; // time of last ack
inline unsigned long TSLA() {
    return millis() - TOLA;
} // time since last ack

void setup_mkr1310() {

    // ARDUINO PIN INITIALIZATION

    analogReadResolution(ADC_BITS);

    pinMode(PIN_LORAMODE, INPUT_PULLUP);
    pinMode(PIN_SW1, INPUT_PULLUP);
    pinMode(PIN_BATADC, INPUT);
    pinMode(PIN_INTERRUPT, INPUT_PULLDOWN);
    pinMode(PIN_STATUSLED, INPUT);
    pinMode(PIN_ERRORLED, OUTPUT);
    pinMode(LORA_IRQ, INPUT);

    pinMode(PIN_DHT, OUTPUT);

    indicateOn();
    errorOff();

    // RTC

    rtc.begin();
    if (SET_RTC) {
        rtc.setEpoch(COMPILE_TIME);
        rtc.disableAlarm();
    }

    if (DEBUG) {
        Serial.begin(SERIALBAUD);
        while (!Serial && millis() < SERIALTIMEOUT)
            yield();
    }
    timeStamp();
    Serial.println(F("Serial Interface Connected!"));

    // ADXL INITIALIZATION

    while (++adxlAttempts <= ADXL_CONNECTION_TIMEOUT) { // may take 2+ attempts

        adxl = new ADXL345(PIN_ADXLCS1);

        fullResetADXL(adxl);

        // check for life
        AccelData dum;
        adxl->getInterruptSource();
        adxl->readAccel(&dum.x, &dum.y, &dum.z);
        if ((abs(dum.x) + abs(dum.y) + abs(dum.z)) <= 0) {
            Serial.println(F("No ADXL on SPIBUS, retrying..."));
            delay(10);
        }
        else
            break;
    }
    if (adxlAttempts > ADXL_CONNECTION_TIMEOUT) {
        Serial.println(F("Error: ADXL Appears Offline"));
        // while (1)
        //     ERROR_OUT(ERROR_ADXL345);
        //  todo: more gracefully handle (ex. don't run calibration)
    }
    adxlMode(adxl, ADXL_MOTION);

    timeStamp();
    Serial.println(F("ADXL Online!"));

    // LORA INITIALIZATION

    // calculate which channel to use first
    // the final product should determine this by other methods
    long freq;
    if (digitalRead(PIN_LORAMODE)) {
        freq = LoRaChannelsUS[63];
    }
    else {
        freq = LoRaChannelsEU[7];
    }

    timeStamp();
    Serial.print(F("Using "));
    Serial.print(freq / 1000000.0, 1);
    Serial.println(F("MHz channel"));

    if (!LoRa.begin(freq)) {
        Serial.println(F("Error: LoRa Module Failure"));
        while (1)
            ERROR_OUT(ERROR_NO_LORA);
    }

    LoRa.setSpreadingFactor(SPREADFACTOR);
    LoRa.setSignalBandwidth(CHIRPBW);
    LoRa.setCodingRate4(CODERATE);
    LoRa.setPreambleLength(PREAMBLELEN);
    LoRa.setSyncWord(SYNCWORD);
    LoRa.setTxPower(LORA_POWER, PA_OUTPUT_PA_BOOST_PIN);
    LoRa.setGain(RECEIVER_GAINMODE);

    timeStamp();
    if (USING_CRC) {
        LoRa.enableCrc();
        Serial.print(F("CRC Enabled: "));
    }
    else {
        LoRa.disableCrc();
        Serial.print(F("CRC Disabled: "));
    }
    Serial.println(F("LoRa Module Operational!"));

    // POWER MANAGER INITIALIZATION

    PMIC.begin();
    // here
    PMIC.end();
    timeStamp();
    Serial.println(F("Power Manager IC Initialized!"));

    // TEMPERATURE SENSOR (IF AVAILABLE)
    tSensor = new DHT(PIN_DHT, DHT11);
    tSensor->begin();
    delay(2000); // required after setup
    if (!isnan(tSensor->readTemperature(false))) {
        timeStamp();
        Serial.println(F("Temperature Sensor Detected"));
    }
    else {
        timeStamp();
        Serial.println(F("No Temperature Sensor"));
    }

    // Calculate & Print FIR
    populateFIR(LPF_FIR);

    // CALIBRATE GRAVITATIONAL BIAS
    DC_offset = getDCOffset(adxl, CALIBRATION_TIME_SLICE);
    TOLC      = millis();

    // COLLECT SOME STRUCT PARAMETERS

    mnd.ID         = MY_IDENTIFIER;
    mnd.packetnum  = 0;
    mnd.all_states = 0x0F80E402;

    // ISR ATTACHMENT
    motionDetected = false;
    LowPower.attachInterruptWakeup(
        digitalPinToInterrupt(PIN_INTERRUPT), wakeuphandler, RISING); // wake up on pin 7 rising

    // acknowledgement attach
    LoRa.onReceive([](int sz) -> void { ackFlag = sz; });

    // FINALIZE
    indicateOff();
    timeStamp();
    Serial.println(F("Node Setup Complete!"));

    if (!DEBUG) {
        Serial.println(F("Shutting down external serial interface."));
        if (Serial)
            Serial.end();
        USBDevice.detach();
    }
}
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

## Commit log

2023-01-18 initial board configuration
2023-01-18 create multi-board source files
2023-01-18 configured for multiple boards
2023-01-20 resolve libraries as chain+
2023-01-20 only define prototypes for the current environment
2023-01-23 add low power library
2023-01-27 include arduino
2023-02-01 add accelerometer library for testing
2023-02-01 fix compiler error by using constexpr for casted const doubles
    [dfm_mkr1310.h]
2023-02-07 lower power for hub
2023-02-07 change TOA to us measure. add CRC and mode switch set TX and indicator
2023-02-08 central node parser corrections first stage
    [dfm_recv_mkr1310.cpp]
2023-02-09 clean up string printing
2023-02-10 additional serial prints debug
2023-02-11 experiment with interrupt based LoRa
2023-02-13 add pessimistic/best case values
2023-02-19 upload test data
    [scope_0.csv, scope_1.csv, scope_2.csv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]
2023-02-27 run simple accelerometer print test
2023-03-01 minor correction to deprecated function
    [dfm_utils.cpp]
2023-03-01 added serial printing to main file
2023-03-01 define CS pin
2023-03-03 collapse test framework to multi-function file
2023-03-03 move to make board-agnostic
2023-03-03 add plain nano env; global test filter
2023-03-03 Added test_5 for the detection algorithm. Detection algorithm records the last 1000 inputs from the accelerometer.
2023-03-03 take power measurement
2023-03-04 Added Accelerometer to Matlab to Test
2023-03-04 move toli to correct location
    [tests.cpp]
2023-03-04 add and test simple accelerometer data viewer
2023-03-04 sort tests by category
    [scope_0.csv, scope_1.csv, scope_2.csv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]
2023-03-06 update transmitter value, battery size
2023-03-09 move interpreter folder up one level
    [scope_0.csv, scope_1.csv, scope_2.csv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]
2023-03-10 add plots for power, relative power at each transmission
2023-03-12 battery logging test
2023-03-20 tests for PCB, thresholds
2023-03-22 change test thresh to pcb pins
2023-03-22 add battery test
2023-03-28 update constants, error codes
    [dfm_mkr1310.h, dfm_utils.cpp]
2023-03-30 add consts, fix severity setting
    [dfm_mkr1310.h, dfm_utils.cpp]
2023-03-30 prints for debugging
2023-03-31 started on DC offset/calibration code
2023-04-03 tiem of last realtime clock and time of last sample added
2023-04-05 sleep mode fixes; adxlMode code block
    [dfm_mkr1310.cpp, dfm_mkr1310.h, dfm_utils.cpp]
2023-04-07 update to current receiver
2023-04-07 time stamp code, debug statements, inactivity prototype
2023-04-08 better error checking in DC calculation
    [dfm_utils.cpp]
2023-04-08 add temperature sensor, remove some debug statements
2023-04-10 dividing line between device statuses
2023-04-12 finite filter tuning module
2023-04-12 implement FIR LPF, timing fixes
    [dfm_mkr1310.cpp]
2023-04-14 create plots for chamber test
2023-04-14 moved FIR and Prints to Functions
2023-04-16 print message adjustments, allow detection in limbo period
2023-04-17 timestamp printing of FIR values
2023-04-17 clean up print statements
2023-04-19 fix padding on hex printing
    [dfm_mkr1310.cpp]
2023-04-21 move to arduino compatible folder
2023-04-27 Add files via upload
    other useful files
    [BOM_PCB_DFM PCB_2023-04-27.csv, Board_Power_1.xlsx, Capstone Testing Software.xlsx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]
